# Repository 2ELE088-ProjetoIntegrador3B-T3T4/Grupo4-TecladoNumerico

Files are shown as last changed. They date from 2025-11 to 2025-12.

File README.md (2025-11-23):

# Grupo 4 - TecladoNumerico

Grupo 4 - Teclado Numérico
Composto por Gabriel Trindade Benatti Frizzo, Matheus Rodrigues Garcia e Vitor Hugo Domingues Bogo

## Motivação e justificativa

A escolha do projeto de teclado numérico com switches mecânicos - o componente que efetivamente realiza o acionamento da tecla - se deu pela sua complexidade balanceada, bem como a sua utilidade no cotidiano.

Os membros do grupo veem o periférico como um bem que pode ser usado para auxiliar usuários que trabalham em ambientes laboratoriais e industrias de áreas com grande utilização de números, operações e símbolos matemáticos.

Não só isso mas com pequenas alterações existe a possibilidade de diferenciadas empresas utilizarem o teclado da forma que desejarem, podendo modificar o produto de forma relativamente simples em busca de remapear as teclas para se adequar a situação. Tais modificações incluem, mas não estão limitadas a modificar o digito que cada tecla se referencia, realizar aperto de 2 ou mais teclas com apenas 1 tecla ou mapeamento de comandos internos do sistema operacional, podendo assim realizar trabalhos repetitivos em busca de facilitar a vida do usuário.

Quanto ao uso de switches mecânicos, o uso se dá pela alta durabilidade e confiabilidade em relação ao sistema de teclados por membrana.

##  Objetivos

É esperado que sejam atingidos alguns critérios mínimos para a melhor experiência do usuário, como:

- Personalização e ergonomia: O teclado conta com o sistema de teclas hot-swappable, ou seja, switches facilmente trocáveis por conta da falta de solda, e sim por serem encaixadas manualmente na PCB do teclado.
  - Isso permite que o usuário faça a troca sem grandes dificuldades das teclas de acordo com sua preferência ou necessidade, desde que a pinagem dos novos switches seja compatível com a presente na PCB.

- Os switches são fabricados em diversas forças de atuação, distâncias mínimas e máximas para o clique, níveis de som ao pressionar as teclas e sensações táteis distintas, tornando sua variabilidade enorme.

- O sistema mecânico também possibilita a troca das keycaps - peça que cobre o topo das teclas, rotulando a função de cada uma - à bel-prazer do consumidor, de acordo com sua estética, material e topografia.
  - Com esses dois últimos tópicos buscamos não só dar uma ferramenta nas mãos do usuário como também deixamos a possibilidade de customização própria do usuário em aberto, caso esse venha a desejar.
    > A intenção é que o produto venha completamente funcional para o usuário, que se quiser fazer modificações terá de buscar por si só, aproveitando das comodidades oferecidas para a customização.

- Durabilidade e performance: O estimado para o teclado é que suporte entre 30 e 70 milhões de cliques por tecla, como é estimado para qualquer teclado mecânico.

## Descrição e Funcionamento do Sistema

O sistema tem uma funcionalidade simples, afinal seu único objetivo é "enviar um ou mais sinais para um computador, e que esses sinas sejam entendidos com uma letra do alfabeto e que faça parte do QWERTY"

Portanto, para atingir o objetivo pretendido, o projeto segue a seguinte lógica de funcionamento:

- o microcontrolador STM32F103C8T6 é o centro do projeto, ele será responsável por dialogar com o computador pela porta USB-C, e interpretar o  comportamento da matriz de teclas para saber quando uma foi apertada ou não.
- A matriz de teclas é responsável é onde as teclas estão arranjadas em linhas e colunas (em nosso caso, 3 colunas e 5 linhas), com isso podemos gastar menos GPIOs do microcontrolador e ainda assim ter uma boa quantidade de teclas.
- Por fim o outro componente principal é a entrada USB-C, cujo dela será alimentado todo o sistema da placa e a conversação entre o microcontrolador e o computador é possibilitada.

## Resultados Esperados

O resultado final é um teclado numérico robusto, modular e personalizável, que pode ser utilizado tanto como um periférico de computador quanto como parte de sistemas embarcados, calculadoras, painéis de controle industrial, cofres eletrônicos e sistemas de autenticação.

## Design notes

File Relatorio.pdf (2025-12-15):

Título do artigo
Montagem de um teclado numérico utilizando um STM32F103C8T6

Autores
Gabriel Trindade Benatti Frizzo, Matheus Rodrigues Garcia*, Vitor Hugo Domingues Bogo.

Afiliações
Universidade Estadual de Londrina (UEL), Rodovia Celso Garcia Cid, PR-445, Km 380 – Campus Universitário, Londrina – PR, 86057-970, Brasil.

Resumo
O produto consiste em um teclado numérico mecânico com layout de teclas 3x5 com conexão por fio. O teclado é controlado por um STM32F103C8T6 e usa sistema hot-swappable de teclas.

Palavras-chave
Teclado numérico 3×5, sistemas embarcados, sensores de baixo custo.

Tabela de especificações

Nome do hardware | Nome do hardware que você desenvolveu/customizou
Area tem ´ ática | • Geral
Tipo de hardware | • Engenharia elétrica e ciência da computação
Análogo comercial mais próximo | Numérico matricial comercial (3×5)
Licença de código aberto | CERN Open Hardware License Version 2 – Permissive (CERN-OHL-P v2).
Custo do hardware | Aproximadamente 20–30 USD.
Repositório dos arquivos-fonte | https://github.com/2ELE088-ProjetoIntegrador3B-T3T4/Grupo4-TecladoNumerico (https://github.com/2ELE088-ProjetoIntegrador3B-T3T4/Grupo4-TecladoNumerico)

### 1. Hardware no contexto

O hardware desenvolvido consiste em um teclado mecânico programável baseado no microcontrolador, o qual é o STM32F103C8T6. Ele se enquadra na categoria de dispositivos HID (Human Interface Device) abertos, permitindo total reprodutibilidade e modificação por parte do usuário.
Projetos de hardware aberto semelhantes incluem teclados amplamente utilizados em comunidades maker, como o Ferris, Corne, Lily58 e outros dispositivos baseados em firmwares open source como QMK e ZMK. Assim como esses projetos, o teclado apresentado oferece esquemáticos, arquivos Gerber e firmware totalmente acessíveis.
Em contraste, teclados proprietários amplamente disponíveis no mercado como os modelos da Keychron, Logitech, Corsair e Razer geralmente não oferecem acesso aos arquivos de projeto também limitam a personalização do firmware e possuem componentes que não podem ser substituídos ou modificados pelo usuário. Esse projeto é diferente por sua total abertura, simplicidade de fabricação e possibilidade de customização tanto eletrônica quanto mecânica.
Dessa forma, o hardware se enquadra em dispositivos abertos projetados para facilitar estudos de microcontroladores, experimentação em eletrônica digital e desenvolvimento de interfaces personalizadas, mantendo compatibilidade com padrões HID.

### 2. Descrição do hardware

Ao contrário de teclados comerciais de função única, este hardware opera em três camadas de customização simultâneas:
Camada Física (Hot-Swappable): O sistema de soquetes permite que qualquer usuário, sem conhecimento de solda, troque os interruptores mecânicos em segundos. Isso possibilita adaptar a força de atuação (de 35g a 95g), tipo de feedback (tátil, linear, clique) e som conforme a preferência do usuário ou necessidade (ex.: laboratório silencioso vs. ambiente industrial).
Camada de Firmware: O teclado roda o firmware de código aberto, com suporte à interface ST-Link para reprogramação em tempo real. Cada tecla pode ser remapeada dinamicamente para qualquer código, macro ou combinação complexa.
Camada de Aplicação: A interface física é separada da lógica de aplicação, permitindo que o mesmo hardware sirva como controle para diferentes softwares (ImageJ, LabView, Python scripts) com uma certa reprogramação do software do teclado.

Arquivos de projeto

- Os arquivos completos de projeto estão disponíveis no repositório GitHub:
Repositório do projeto no GitHub (https://github.com/2ELE088-ProjetoIntegrador3B-T3T4/Grupo4-TecladoNumerico)

Arquivos CAD: Projeto completo no Altium Designer, incluindo esquemático, layout da PCB e arquivos de fabricação (Gerber) na pasta /Teclado/Project Outputs for teclado.

Impressão 3D: Arquivos de modelagem 3D da caixa do teclado, fornecidos em formatos STL e STEP na pasta /3D.

Eletrônica: Layouts, esquemáticos e bibliotecas relacionados ao hardware na pasta /Teclado/.

Software e firmware: Projeto STM32CubeIDE com o firmware desenvolvido para o controlador STM32F103C8T6, localizado na pasta /Firmware.

### 3. Resumo dos arquivos de projeto

Nome do arquivo de projeto | Tipo de arquivo | Descrição do arquivo
teclado/SqTeclado.SchDoc | CAD (Altium) | Esquemático completo do teclado numérico.
teclado/PCBtc.PcbDoc | CAD (Altium) | Layout da PCB do teclado.
Gerber Files.zip | Gerber | Arquivos de fabricação para PCB.
Firmware/.project | Firmware (CubeIDE) | Código-fonte para o STM32F103C8T6.
3D/CaixaTeclado.stl | 3D (STL) | Modelo para impressão 3D da caixa do teclado.
3D/TampaTeclado.stl | 3D (STL) | Tampa da caixa do teclado para impressão 3D.
3D/Keycap.stl | 3D (STL) | Modelo para impressão 3D das keycaps uti-lizadas no teclado.
3D/Teclado.step | 3D (STEP) | Modelo para 3D do teclado.
README.md | Documentação | Instruções gerais e organização do repositório.

Cada arquivo listado acima está detalhado no repositório GitHub.

Bill of materials

### 4. Resumo da Bill of materials

Designador | Componente | Quan tidade | Custo por unidade - moeda | Custo total -moeda | Fonte do material | Tipo de material
C5, C8 | CL10B105KP8NNNC | 2 | 0.005 USD | 0.05 USD | Digi-Key (https://www.digikey.com.br/pt/products/detail/samsung-electro-mechanics/CL10B105KP8NNNC/3887604) | -Cerâmica
C1, C2, C3, C4, C9, C12, C13 | CC0603KRX7R7BB104 | 7 | 0.006 USD | 0.06 USD | Digi-Key (https://www.digikey.com.br/pt/products/detail/yageo/CC0603KRX7R7BB104/302822) | -Cerâmica
R2, R4, R9, R10, R11, R12, R13, R14 | CRCW060310K0FKEA | 8 | 0.03 USD | 0.3 USD | Digi-Key (https://www.digikey.com.br/pt/products/detail/vishay-dale/CRCW060310K0FKEA/1174782) | -Metal
C6, C7 | CL05C330JB5NNNC | 2 | 0.003 USD | 0.03 USD | Digi-Key (https://www.digikey.com.br/pt/products/detail/samsung-electro-mechanics/CL05C330JB5NNNC/3886930) | -Cerâmica
C10 | CL10B223KB8WPNC | 1 | 0.1 USD | 0.1 USD | Digi-Key (https://www.digikey.com.br/pt/products/detail/samsung-electro-mechanics/CL10B223KB8WPNC/5961018) | -Cerâmica
J1 | SBH11-PBPC-D10-ST-BK | 1 | 0.41 USD | 0.41 USD | Digi-Key (https://www.digikey.com.br/pt/products/detail/sullins-connector-solutions/SBH11-PBPC-D10-ST-BK/1990065) | -Metal
Y1 | ECS-80-20-5PXDU-TR | 1 | 0.45 USD | 0.45 USD | Digi-Key (https://www.digikey.com.br/pt/products/detail/ecs-inc/ECS-80-20-5PXDU-TR/1693466) | -Cerâmica
D1–D15 | 1N4148WX-TP | 15 | 0.061 USD | 0.915 USD | Digi-Key (https://www.digikey.com.br/pt/products/detail/mcc-micro-commercial-components/1N4148WX-TP/717197) | -Semicondutor
F1 | ERBRD0R50X | 1 | 0.29 USD | 0.29 USD | Digi-Key (https://www.digikey.com.br/pt/products/detail/panasonic-electronic-components/ERB-RD0R50X/2796780) | -Metal
U2–U4, U6–U17 | 4958 | 1 | 4.95 USD | 4.95 USD | Digi-Key (https://www.digikey.com.br/pt/products/detail/adafruit-industries-llc/4958/13997772) | -Metal
U5 | STM32F103C8T6 | 1 | 6.08 USD | 6.08 USD | Digi-Key (https://www.digikey.com.br/pt/products/detail/stmicroelectronics/STM32F103C8T6/1646338) | -Semicondutor
C11 | LMK107BBJ106MALT | 1 | 0.08 USD | 0.08 USD | Digi-Key (https://www.digikey.com.br/pt/products/detail/taiyo-yuden/LMK107BBJ106MALT/3662195) | -Cerâmica
R6, R7 | RK73H1ETTP5101F | 2 | 0.1 USD | 0.2 USD | Digi-Key (https://www.digikey.com.br/pt/products/detail/koa-speer-electronics-inc/RK73H1ETTP5101F/9844118) | -Metal
R5 | ERJ-3EKF1004V | 1 | 0.1 USD | 0.1 USD | Digi-Key (https://www.digikey.com.br/pt/products/detail/panasonic-electronic-components/ERJ-3EKF1004V/196033) | -Semicondutor
R1 | ERA-2AEB152X | 1 | 0.1 USD | 0.1 USD | Digi-Key (https://www.digikey.com.br/pt/products/detail/panasonic-electronic-components/ERA-2AEB152X/1706009) | -Semicondutor
U19 | RT9193-33GB | 1 | 0.17732 USD | 531.96 USD | Digi-Key (https://www.digikey.com.br/pt/products/detail/richtek-usa-inc/RT9193-33GB/2470048) | -Semicondutor
X1–X15 | MX1A-C1NN | 15 | 1.25 USD | 18.75 USD | Digi-Key (https://www.digikey.com.br/pt/products/detail/cherry-americas-llc/mx1a-c1nn/16998) | -Metal
U1 | USB4110-GF-A | 1 | 1.23 USD | 1.23 USD | Digi-Key (https://www.digikey.com.br/pt/products/detail/gct/USB4110-GF-A/10384547) | -Semicondutor
U18 | USBLC6-2SC6 | 1 | 0.36 USD | 0.36 USD | Digi-Key (https://www.digikey.com.br/pt/products/detail/stmicroelectronics/USBLC6-2SC6/1040559) | -Semicondutor
R3, R8 | CR0402AJ/-000GAS | 2 | 0.1 USD | 0.2 USD | Digi-Key (https://www.digikey.com.br/pt/products/detail/bourns-inc/CR0402AJ-000GAS/10240110) | -Metal

### 5. Instruções de construção

1. Fabricação da PCB
- Utilize os arquivos Gerber disponibilizados em Gerber Files/.
- Envie os arquivos para um fabricante de PCB (por exemplo, JLCPCB, PCBWay, OSH Park ou equivalente).
- Recomendações sugeridas:

– Espessura da placa: 1.6 mm
– Máscara de solda: ”””””””””””””””””””””””””””””””verde (ou outra cor disponível)
– Acabamento superficial: HASL ou ENIG
- Opcionalmente, solicite a montagem SMT direta pelo fabricante, utilizando a Bill of Materials e o arquivo de posicionamento.
2. Montagem dos componentes eletrônicos

Há duas possibilidades de montagem:

### 2.1. Montagem pelo fabricante

- A maioria dos componentes SMD pode ser montada automaticamente.
- Esta opção é recomendada para precisão e confiabilidade.

### 2.2. Montagem manual pelo usuário

- Solde primeiro os componentes SMD (resistores, capacitores, diodos e ICs).
- Utilize ferro de solda entre 300–350 °C, com ponta fina.
- Após isso, solde os componentes PTH, como:

– Switches mecânicos MX,
– Conector USB,
– Header J1.
- Verifique cuidadosamente a polaridade dos seguintes componentes:

– Diodos 1N4148WX-TP,
– Regulador U19,
– Microcontrolador STM32F103C8T6,
– Proteção USBLC6-2SC6.
- Antes de energizar a placa, confira a ausência de curtos-circuitos.
3. Programação do firmware
- Abra o projeto disponibilizado em Firmware/ no STM32CubeIDE.
- Conecte um programador ST-Link ao conector J1.
- Compile e carregue o firmware no microcontrolador STM32F103C8T6.
- Após a gravação, desconecte o programador e alimente a placa via USB-C.

4. Montagem mecânica da caixa
- Imprima os arquivos 3D da caixa e da tampa disponíveis na pasta 3D/.
- Insira a PCB na caixa, alinhando os furos aos suportes internos.
- Utilize parafusos M3 para fixar a PCB.
- Encaixe a tampa superior.
- Instale as keycaps nos switches MX.
5. Pontos de atenção e segurança
- Evite contato com pads sensíveis durante a soldagem para prevenir danos eletrostáticos.
- Não exceda temperaturas adequadas de soldagem para evitar descolamento de trilhas.
- Utilize óculos de proteção ao soldar ou realizar cortes.
- Inspecione visualmente a placa antes de energizá-la.
- Mantenha a placa afastada de líquidos e fontes de calor extremos.

### 6. Instruções de operação

Procedimento de Operação

- Conecte o teclado ao computador por meio da porta USB-C.O dispositivo será reconhecido automaticamente como um teclado padrão (HID).
- Após a conexão, o teclado estará pronto para uso imediato, não é necessária instalação de drivers extras.
- Pressione qualquer uma das teclas disponíveis, cada acionamento enviará o respectivo código de tecla ao computador.
- Caso o computador não reconheça o dispositivo, remova o cabo USB-C e reconecte-o, verificando também a integridade do cabo.

Cuidados e Segurança

- Evite contato com líquidos. Exposição à água ou outros fluidos pode causar curto-circuito, falha permanente ou risco elétrico.
- Não derrube o produto. Impactos fortes podem danificar a PCB, switches mecânicos, soldas ou o microcontrolador.
- Não aplique força excessiva ao pressionar as teclas; os switches mecânicos possuem limite físico de operação.
- Não tente abrir ou modificar o hardware sem conhecimento técnico, pois isso pode causar danos irreversíveis e perda de garantia.
- Utilize somente cabos USB-C de boa qualidade para garantir alimentação estável e comunicação adequada.

### 7. Validação e caracterização

Validação Funcional

Para demonstrar a operação adequada do hardware, foram realizados testes diretos conectando o teclado a um computador por meio da interface USB-C. O microcontrolador STM32F103C8T6 foi programado para atuar como um dispositivo HID (Human Interface Device), enviando códigos de teclas ao sistema operacional.
Os seguintes procedimentos foram executados:
- Conexão do dispositivo a diferentes computadores (Windows, Linux e MacOS) para verificar reconhecimento automático do teclado.
- Teste individual de todas as 15 teclas mecânicas (switches MX) para garantir detecção correta e ausência de falhas de acionamento.
- Verificação da temporização de debounce via firmware, assegurando que nenhum acionamento múltiplo (bouncing) ocorresse.
- Inspeção visual e elétrica da PCB para confirmar continuidade e ausência de curtos.

A validação confirmou que o teclado é reconhecido corretamente em todos os sistemas testados e que todas as teclas apresentam leitura estável e sem erros.

Caracterização do Desempenho

A caracterização do teclado considerou parâmetros elétricos e mecânicos relevantes:

- Tempo de resposta: menor que 5 ms entre o acionamento da tecla e o envio do código HID.
- Consumo de corrente: aproximadamente 20–35 mA em operação contínua.
- Tensão de operação: 5 V fornecidos via USB.
- Ruído elétrico: filtrado adequadamente por capacitores de desacoplamento, permitindo operação estável.
- Confiabilidade dos switches: vida útil estimada em mais de 50 milhões de acionamentos (característica padrão dos switches MX).
- Precisão da leitura: 100% de detecção de teclas durante testes contínuos.

Capacidades e Limitações

Capacidades:

- Compatibilidade completa com computadores que suportam dispositivos HID via USB.
- Alta durabilidade e sensação tátil devido aos switches mecânicos MX.
- Debounce implementado via firmware, garantindo leitura confiável.
- Baixo consumo de energia devido ao uso do microcontrolador STM32.
- Latência muito baixa, praticamente imperceptível ao usuário.

Limitações:

- Não possui retroiluminação integrada.
- Quantidade fixa de teclas (15), não expansível sem alteração da PCB.
- O dispositivo depende do cabo USB-C para alimentação e operação (não possui bateria).
- Não oferece personalização avançada via software sem recompilar o firmware.

—————————————————————————————————————————

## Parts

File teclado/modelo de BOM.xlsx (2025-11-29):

Designator | LibRef | Footprint
C5, C8 | CL10B105KP8NNNC | cap 105 0603
C1, C2, C3, C4, C9, C12, C13 | CC0603KRX7R7BB104 | Cap 104 0603
R2, R4, R9, R10, R11, R12, R13, R14 | CRCW060310K0FKEA | Resistor 10k 0603
C10 | GRM033R60J223KE01D | cap 223 0603
C6, C7 | CL05C330JB5NNNC | C 33pf 0402
J1 | SBH11-PBPC-D10-ST-BK | Conector 20 pinos p/ programação
Y1 | ECS-80-20-5PXDU-TR | Cristal 8MHz
D1, D2, D3, D4, D5, D6, D7, D8, D9, D10, D11, D12, D13, D14, D15 | 1N4148WX-TP | Diodo
F1 | ERBRD0R50X | Fuse
U2, U3, U4, U6, U7, U8, U9, U10, U11, U12, U13, U14, U15, U16, U17 | 4958 | Suporte Hot-Swap
U5 | STM32F103C8T6 | STM32F103C8T6
C11 | LMK107BBJ106MALT | cap 106 0603
R6, R7 | RK73H1ETTP5101F | R 5.1k 0402
R5 | ERJ-3EKF1004V | R 1Mr 0603
R1 | ERA-2AEB152X | R 1.5k 0402
U19 | RT9193-33GB | Regulador 5v->3v
U1 | USB4110-GF-A | USB-C
U18 | USBLC6-2SC6 | Potege estatica
R3, R8 | CR0402AJ/-000GAS | R0

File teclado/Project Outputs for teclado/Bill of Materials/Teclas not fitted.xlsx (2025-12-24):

Line # | Description | Designator | Quantity | Comment | Supplier Part Number | Supplier Subtotal per Board 1 | Supplier Stock 1 | Supplier Packaging 1 | Supplier Order Qty 1 | Supplier Currency 1 | Manufacturer 1 | Manufacturer Part Number 1 | Manufacturer Lifecycle 1 | Supplier 1 | Supplier Part Number 1 | Supplier Unit Price 1 | Supplier Subtotal 1
 | 10V 1uF X7R ±10% 0603 Multilayer Ceramic Capacitors MLCC - SMD/SMT ROHS | C9, C14 | 2 | CL10B105KP8NNNC | 1276-1946-1-ND | 0.01 | 3540967 | Cut Tape | 10 | USD | Samsung Electro-Mechanics | CL10B105KP8NNNC | Volume Production | DigiKey | 1276-1946-1-ND | 0.005 | 0.05
 | 16V 100nF X7R ±10% 0603 Multilayer Ceramic Capacitors MLCC - SMD/SMT ROHS | C1, C3, C4, C5, C6, C7, C10, C13 | 8 | CC0603KRX7R7BB104 | 311-1088-1-ND | 0.048 | 5424503 | Cut Tape | 10 | USD | Yageo Group | CC0603KRX7R7BB104 | Volume Production | DigiKey | 311-1088-1-ND | 0.006 | 0.06
 | 100Mw Thick Film Resistors 100Ppm/ 5% 1.5K 0603 Chip Resistor Surface Mount Rohs | R3 | 1 | RC0603JR-071K5L | 311-1.5KGRCT-ND | 0.1 | 687335 | Cut Tape | 1 | USD | Yageo Group | RC0603JR-071K5L | Volume Production | DigiKey | 311-1.5KGRCT-ND | 0.1 | 0.1
 | 100mW Thick Film Resistors ±1% ±100ppm/℃ 10kΩ 0603 Chip Resistor - Surface Mount ROHS | R5, R6, R7, R8, R9, R10, R11, R12 | 8 | CRCW060310K0FKEA | 541-10.0KHCT-ND | 0.24 | 2856834 | Cut Tape | 10 | USD | Vishay | CRCW060310K0FKEA | Volume Production | DigiKey | 541-10.0KHCT-ND | 0.03 | 0.3
 | 0603 27 pF 50 V ±1 % Tolerance NP0 SMT Multilayer Ceramic Capacitor | C2, C8 | 2 | CC0603FRNPO9BN270 | 311-3892-1-ND | 0.3 | 50604 | Cut Tape | 2 | USD | Yageo Group | CC0603FRNPO9BN270 | Volume Production | DigiKey | 311-3892-1-ND | 0.15 | 0.3
 | Ceramic Capacitor, Multilayer, Ceramic, 50V, 10% +Tol, 10% -Tol, X7R, +-15% TC, 22nF, Surface Mount, 0603 inch | C11 | 1 | CL10B223KB8WPNC | 1276-6534-1-ND | 0.1 | 841892 | Cut Tape | 1 | USD | Samsung Electro-Mechanics | CL10B223KB8WPNC | Volume Production | DigiKey | 1276-6534-1-ND | 0.1 | 0.1
 | Conn Shrouded Header (4 Sides) HDR 20 POS 2.54mm Solder RA Side Entry Thru-HoleC-Grid Tray | J1 | 1 | 70247-2051 | 23-0702472051-ND | 3.89 | 2615 | Bulk | 1 | USD | Molex | 70247-2051 | Volume Production | DigiKey | 23-0702472051-ND | 3.89 | 3.89
 | Crystal 8MHz ±30ppm (Tol) ±100ppm (Stability) 20pF FUND 60Ohm 2-Pin SMD T/R | Y1 | 1 | ECS-80-20-5PXDU-TR | XC1526CT-ND | 0.45 | 7422 | Cut Tape | 1 | USD | ECS International | ECS-80-20-5PXDU-TR | Volume Production | DigiKey | XC1526CT-ND | 0.45 | 0.45
 | Fuse Chip Fast Acting 0.5A 32V SMD Solder Pad 0603 1.6 X 0.8 X 0.54mm T/R UL/cUL | F1 | 1 | ERB-RE0R50V | P15127CT-ND | 0.31 | 2919 | Cut Tape | 1 | USD | Panasonic | ERB-RE0R50V | Volume Production | DigiKey | P15127CT-ND | 0.31 | 0.31
 | GENERAL PURPOSE CHIP RESISTOR Metal Glaze/thick Film, 0.1W, 0ohm, Surface Mount, 0603 | R4 | 1 | RC0603JR-070RL | 311-0.0GRCT-ND | 0.1 | 2939930 | Cut Tape | 1 | USD | Yageo Group | RC0603JR-070RL | Volume Production | DigiKey | 311-0.0GRCT-ND | 0.1 | 0.1
 | Kailh Switch Sockets For Mx-Compatible Mechanical Keys - 20 Pack |Adafruit 4958 | U2, U3, U4, U6, U7, U8, U9, U10, U11, U12, U13, U14, U16, U17, U18 | 15 | 4958 | 1528-4958-ND | 74.25 | 37 | Bulk | 15 | USD | Adafruit Industries | 4958 | Unknown | DigiKey | 1528-4958-ND | 4.95 | 74.25
 | MCU 32-bit STM32F1 ARM Cortex M3 RISC 64KB Flash 2.5V/3.3V 48-Pin LQFP Tray | U5 | 1 | STM32F103C8T6 | 497-6063-ND | 6.08 | 3373 | Tray | 1 | USD | STMicroelectronics | STM32F103C8T6 | Volume Production | DigiKey | 497-6063-ND | 6.08 | 6.08
 | Multilayer Ceramic Capacitors (High dielectric type), 10V, 10 uF, ± 20 %, 0603, X5R, RoHS | C12 | 1 | LMK107BBJ106MALT | 587-3258-1-ND | 0.08 | 861176 | Cut Tape | 1 | USD | TAIYO YUDEN | LMK107BBJ106MALT | Volume Production | DigiKey | 587-3258-1-ND | 0.08 | 0.08
 | Rectifier Diode Schottky 40V 0.03A 2-Pin SOD-323 T/R / DIODE SCHOTTKY 30V 30MA SOD323 | D1, D2, D3, D4, D5, D6, D7, D8, D9, D10, D11, D12, D13, D14, D15 | 15 | RB751V40T1G | RB751V40T1GOSCT-ND | 1.2 | 326728 | Cut Tape | 15 | USD | onsemi | RB751V40T1G | Volume Production | DigiKey | RB751V40T1GOSCT-ND | 0.08 | 1.2
 | Res Thick Film 0603 5.1K Ohm 1% 0.1W(1/10W) ±100ppm/C Pad SMD T/R | R1, R2 | 2 | RC0603FR-075K1L | 311-5.10KHRCT-ND | 0.014 | 618540 | Cut Tape | 10 | USD | Yageo Group | RC0603FR-075K1L | Volume Production | DigiKey | 311-5.10KHRCT-ND | 0.007 | 0.07
 | RT9193 Series 300 mA 3.3 V Ultra-Low Noise Ultra-Fast CMOS LDO Regulator-SC-70-5 | U19 | 1 | RT9193-33GB | 1028-1014-1-ND |  |  |  |  |  | Richtek | RT9193-33GB | Obsolete
 | USB Connector, 16 Contact(s), Male, Right Angle, Surface Mount Terminal, Locking, Receptacle | U1 | 1 | USB4110-GF-A | 2073-USB4110-GF-A-1-ND | 1.23 | 38043 | Cut Tape | 1 | USD | Global Connector Technology | USB4110-GF-A | Volume Production | DigiKey | 2073-USB4110-GF-A-1-ND | 1.23 | 1.23
 | USBLC6 Series 2 Line 6 V Uni / Bi-Directional ESD Protection - SOT-23-6 | U15 | 1 | USBLC6-2SC6 | 497-5235-1-ND | 0.36 | 126022 | Cut Tape | 1 | USD | STMicroelectronics | USBLC6-2SC6 | Volume Production | DigiKey | 497-5235-1-ND | 0.36 | 0.36

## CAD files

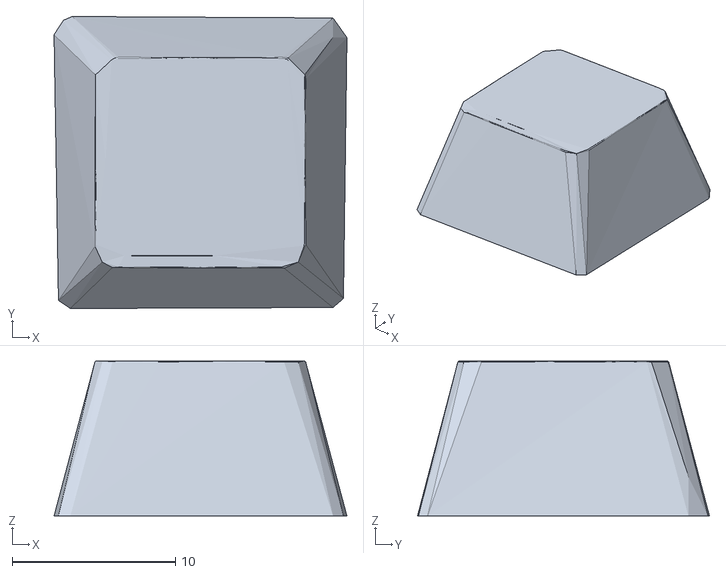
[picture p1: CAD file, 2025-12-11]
3D/Keycap.stl
18.0 x 17.9 x 9.50

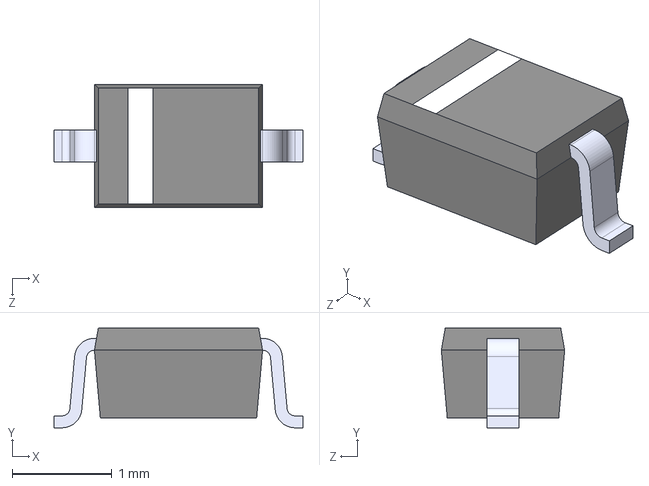
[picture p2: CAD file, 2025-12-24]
teclado/Modelo 3D/Diodo C.step
2.50 x 1.00 x 1.24 mm

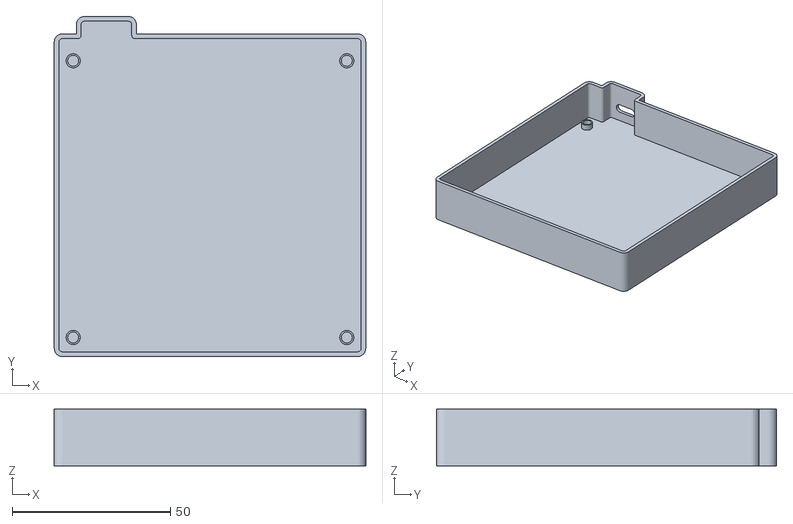
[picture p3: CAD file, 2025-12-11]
3D/CaixaTeclado.stl
98.5 x 107.5 x 18.0

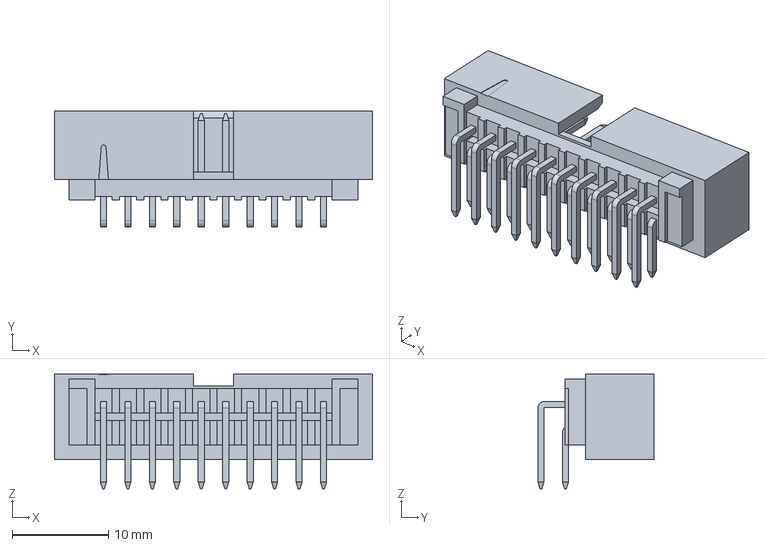
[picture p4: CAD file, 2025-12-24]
teclado/Modelo 3D/conc 20p ang.stp
33.0 x 12.1 x 11.9 mm

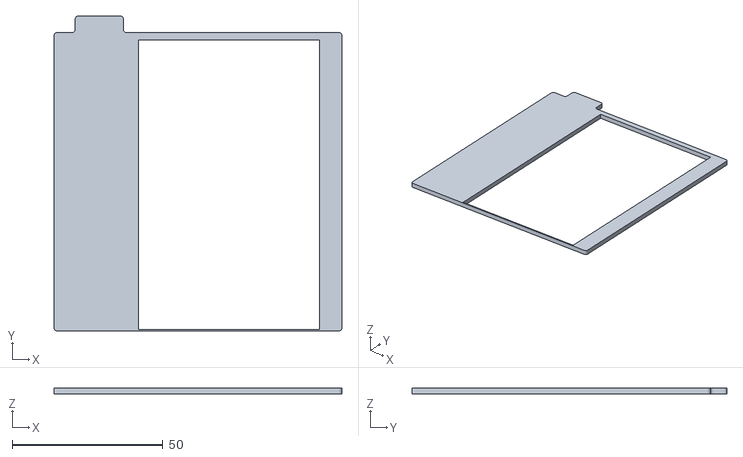
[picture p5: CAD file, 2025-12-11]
3D/TampaTeclado.stl
95.5 x 104.5 x 2.00

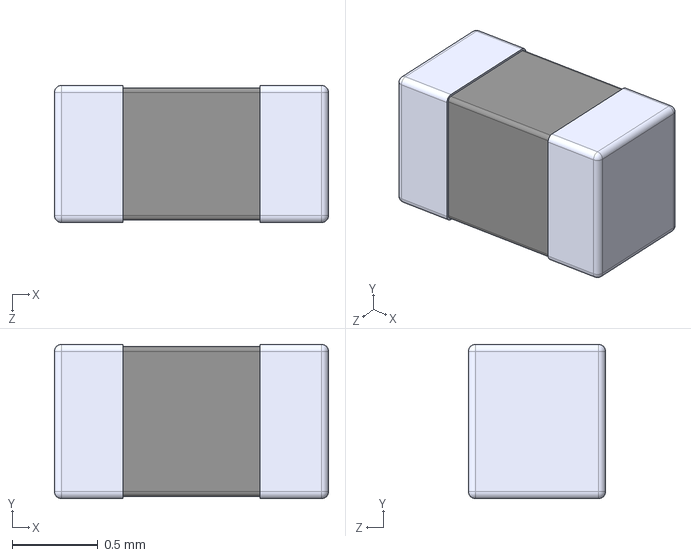
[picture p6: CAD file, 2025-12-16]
teclado/Modelo 3D/cap 27pf 0603.step
1.60 x 0.9 x 0.8 mm

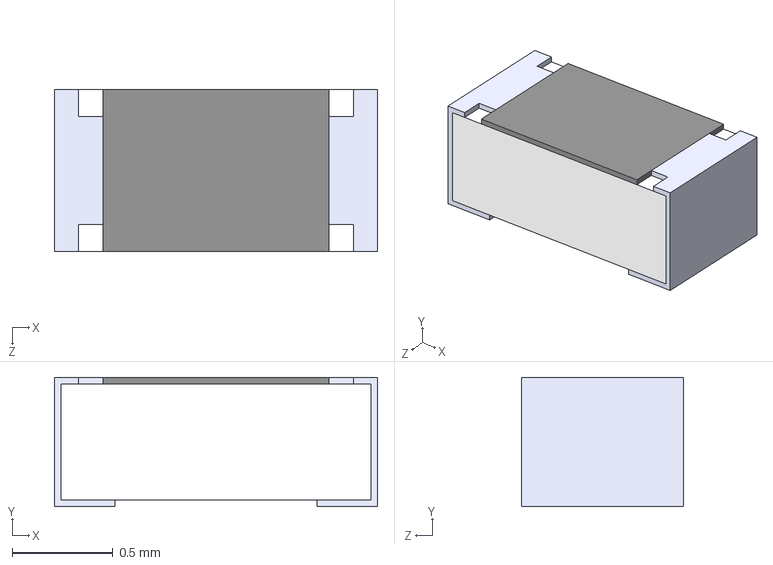
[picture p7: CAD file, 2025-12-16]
teclado/Modelo 3D/F 500ma 0603.STEP
1.60 x 0.64 x 0.8 mm

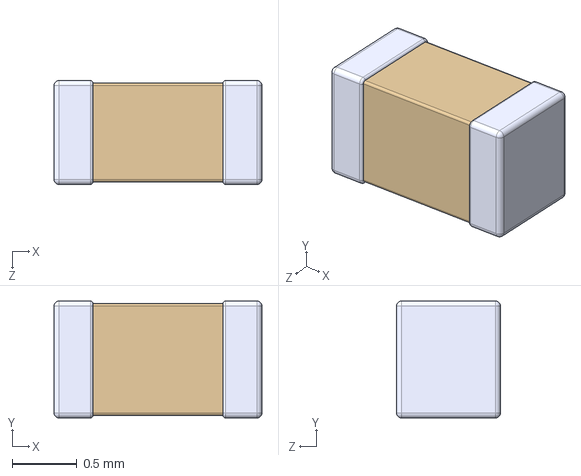
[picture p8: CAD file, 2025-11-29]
teclado/Modelo 3D/cap 223 0603.step
1.60 x 0.9 x 0.8 mm

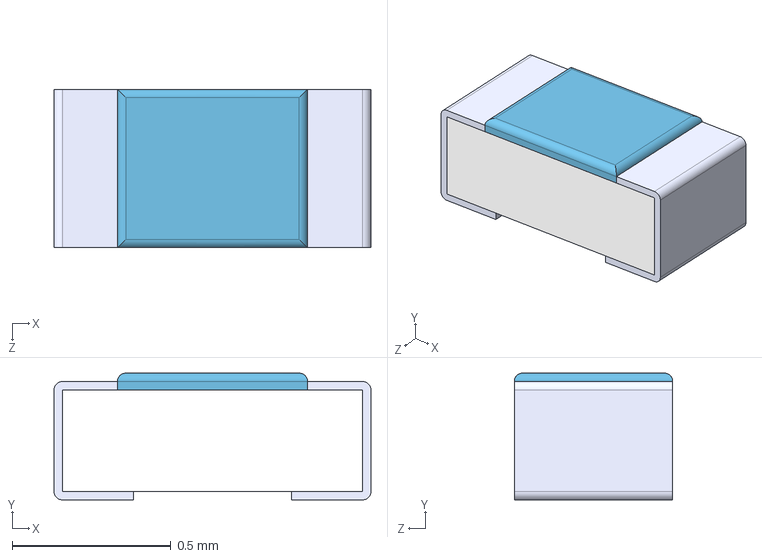
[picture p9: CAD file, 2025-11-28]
teclado/Modelo 3D/R 5.1k 0402.step
1.00 x 0.4 x 0.5 mm

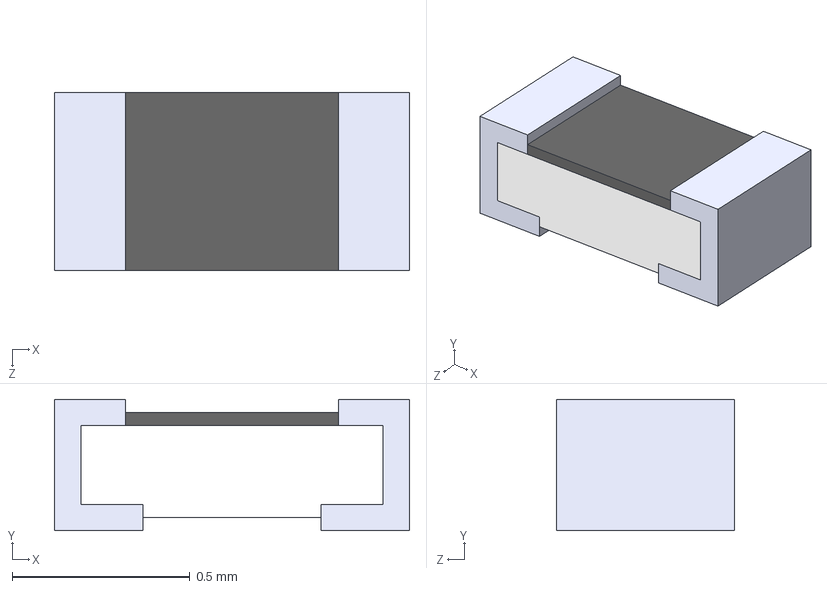
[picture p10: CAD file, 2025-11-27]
teclado/Modelo 3D/R0 0402.STEP
1.00 x 0.37 x 0.5 mm

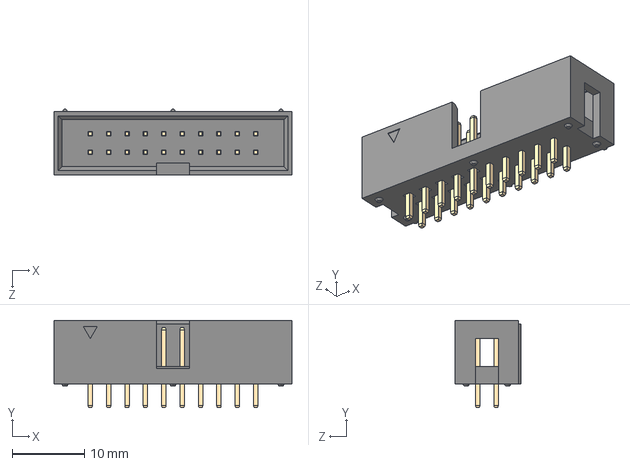
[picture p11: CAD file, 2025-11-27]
teclado/Modelo 3D/conector 20P program.STEP
32.9 x 12.1 x 9.09 mm

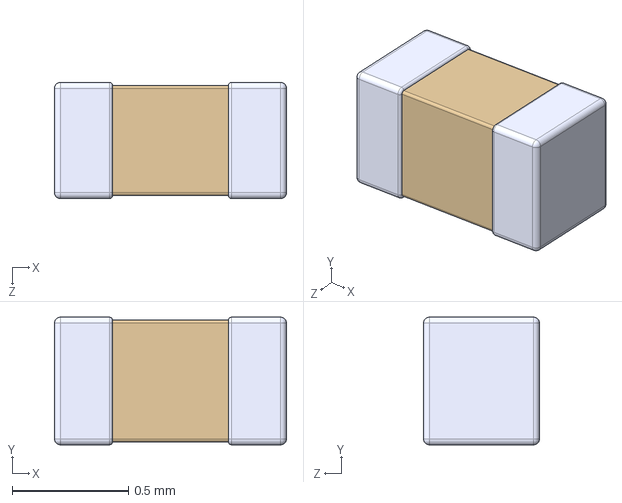
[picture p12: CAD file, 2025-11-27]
teclado/Modelo 3D/C 33pf 0402.STEP
1.00 x 0.55 x 0.5 mm

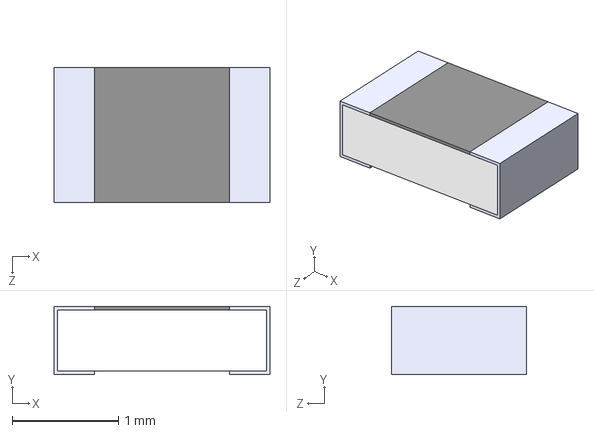
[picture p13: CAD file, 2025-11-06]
teclado/Modelo 3D/R 1.5k 0805.STEP
2.03 x 0.64 x 1.27 mm

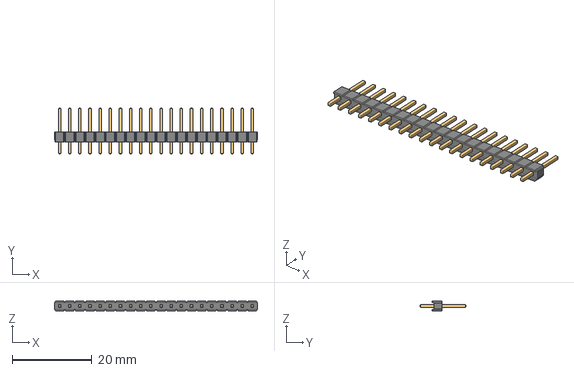
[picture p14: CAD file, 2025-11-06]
teclado/Modelo 3D/conector 1x20.stp
50.8 x 11.5 x 2.54 mm
6130xx11121_PIN x 20

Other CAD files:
teclado/Modelo 3D/con 20p ang 2.stp
teclado/Modelo 3D/swith.STEP
teclado/Modelo 3D/Switche.STEP
teclado/Modelo 3D/fuse.STEP
teclado/Modelo 3D/CRCW060310K0FKEA.STEP
teclado/Modelo 3D/Cap 104 0603.STEP
teclado/Modelo 3D/Diodo.STEP
teclado/Modelo 3D/Protetor curto.step
teclado/Modelo 3D/R 0 0603.STEP
teclado/Modelo 3D/R 1.5k 0402.step
teclado/Modelo 3D/R 1.5k 0603.step
teclado/Modelo 3D/R 1m 0603.step
teclado/Modelo 3D/R 5.1k 0603.step
teclado/Modelo 3D/STM32F103C8T6.STEP
teclado/Modelo 3D/USBC.stp
teclado/Modelo 3D/cap 105 0603.STEP
teclado/Modelo 3D/cap 106 0603.step
teclado/Modelo 3D/cap 20p .STEP
teclado/Modelo 3D/conctor angulado.STEP
teclado/Modelo 3D/conector 3x2.stp
teclado/Modelo 3D/cristal 32,768k.STEP
teclado/Modelo 3D/cristal 8MHZ.STEP
teclado/Modelo 3D/led branco.STEP
teclado/Modelo 3D/led vermelho.step
teclado/Modelo 3D/micro usb.STEP
teclado/Modelo 3D/regulador.STEP
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

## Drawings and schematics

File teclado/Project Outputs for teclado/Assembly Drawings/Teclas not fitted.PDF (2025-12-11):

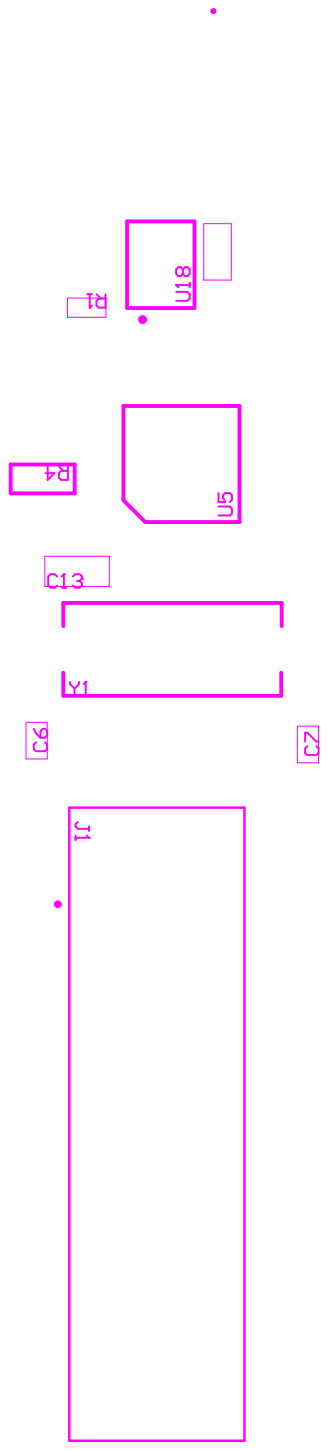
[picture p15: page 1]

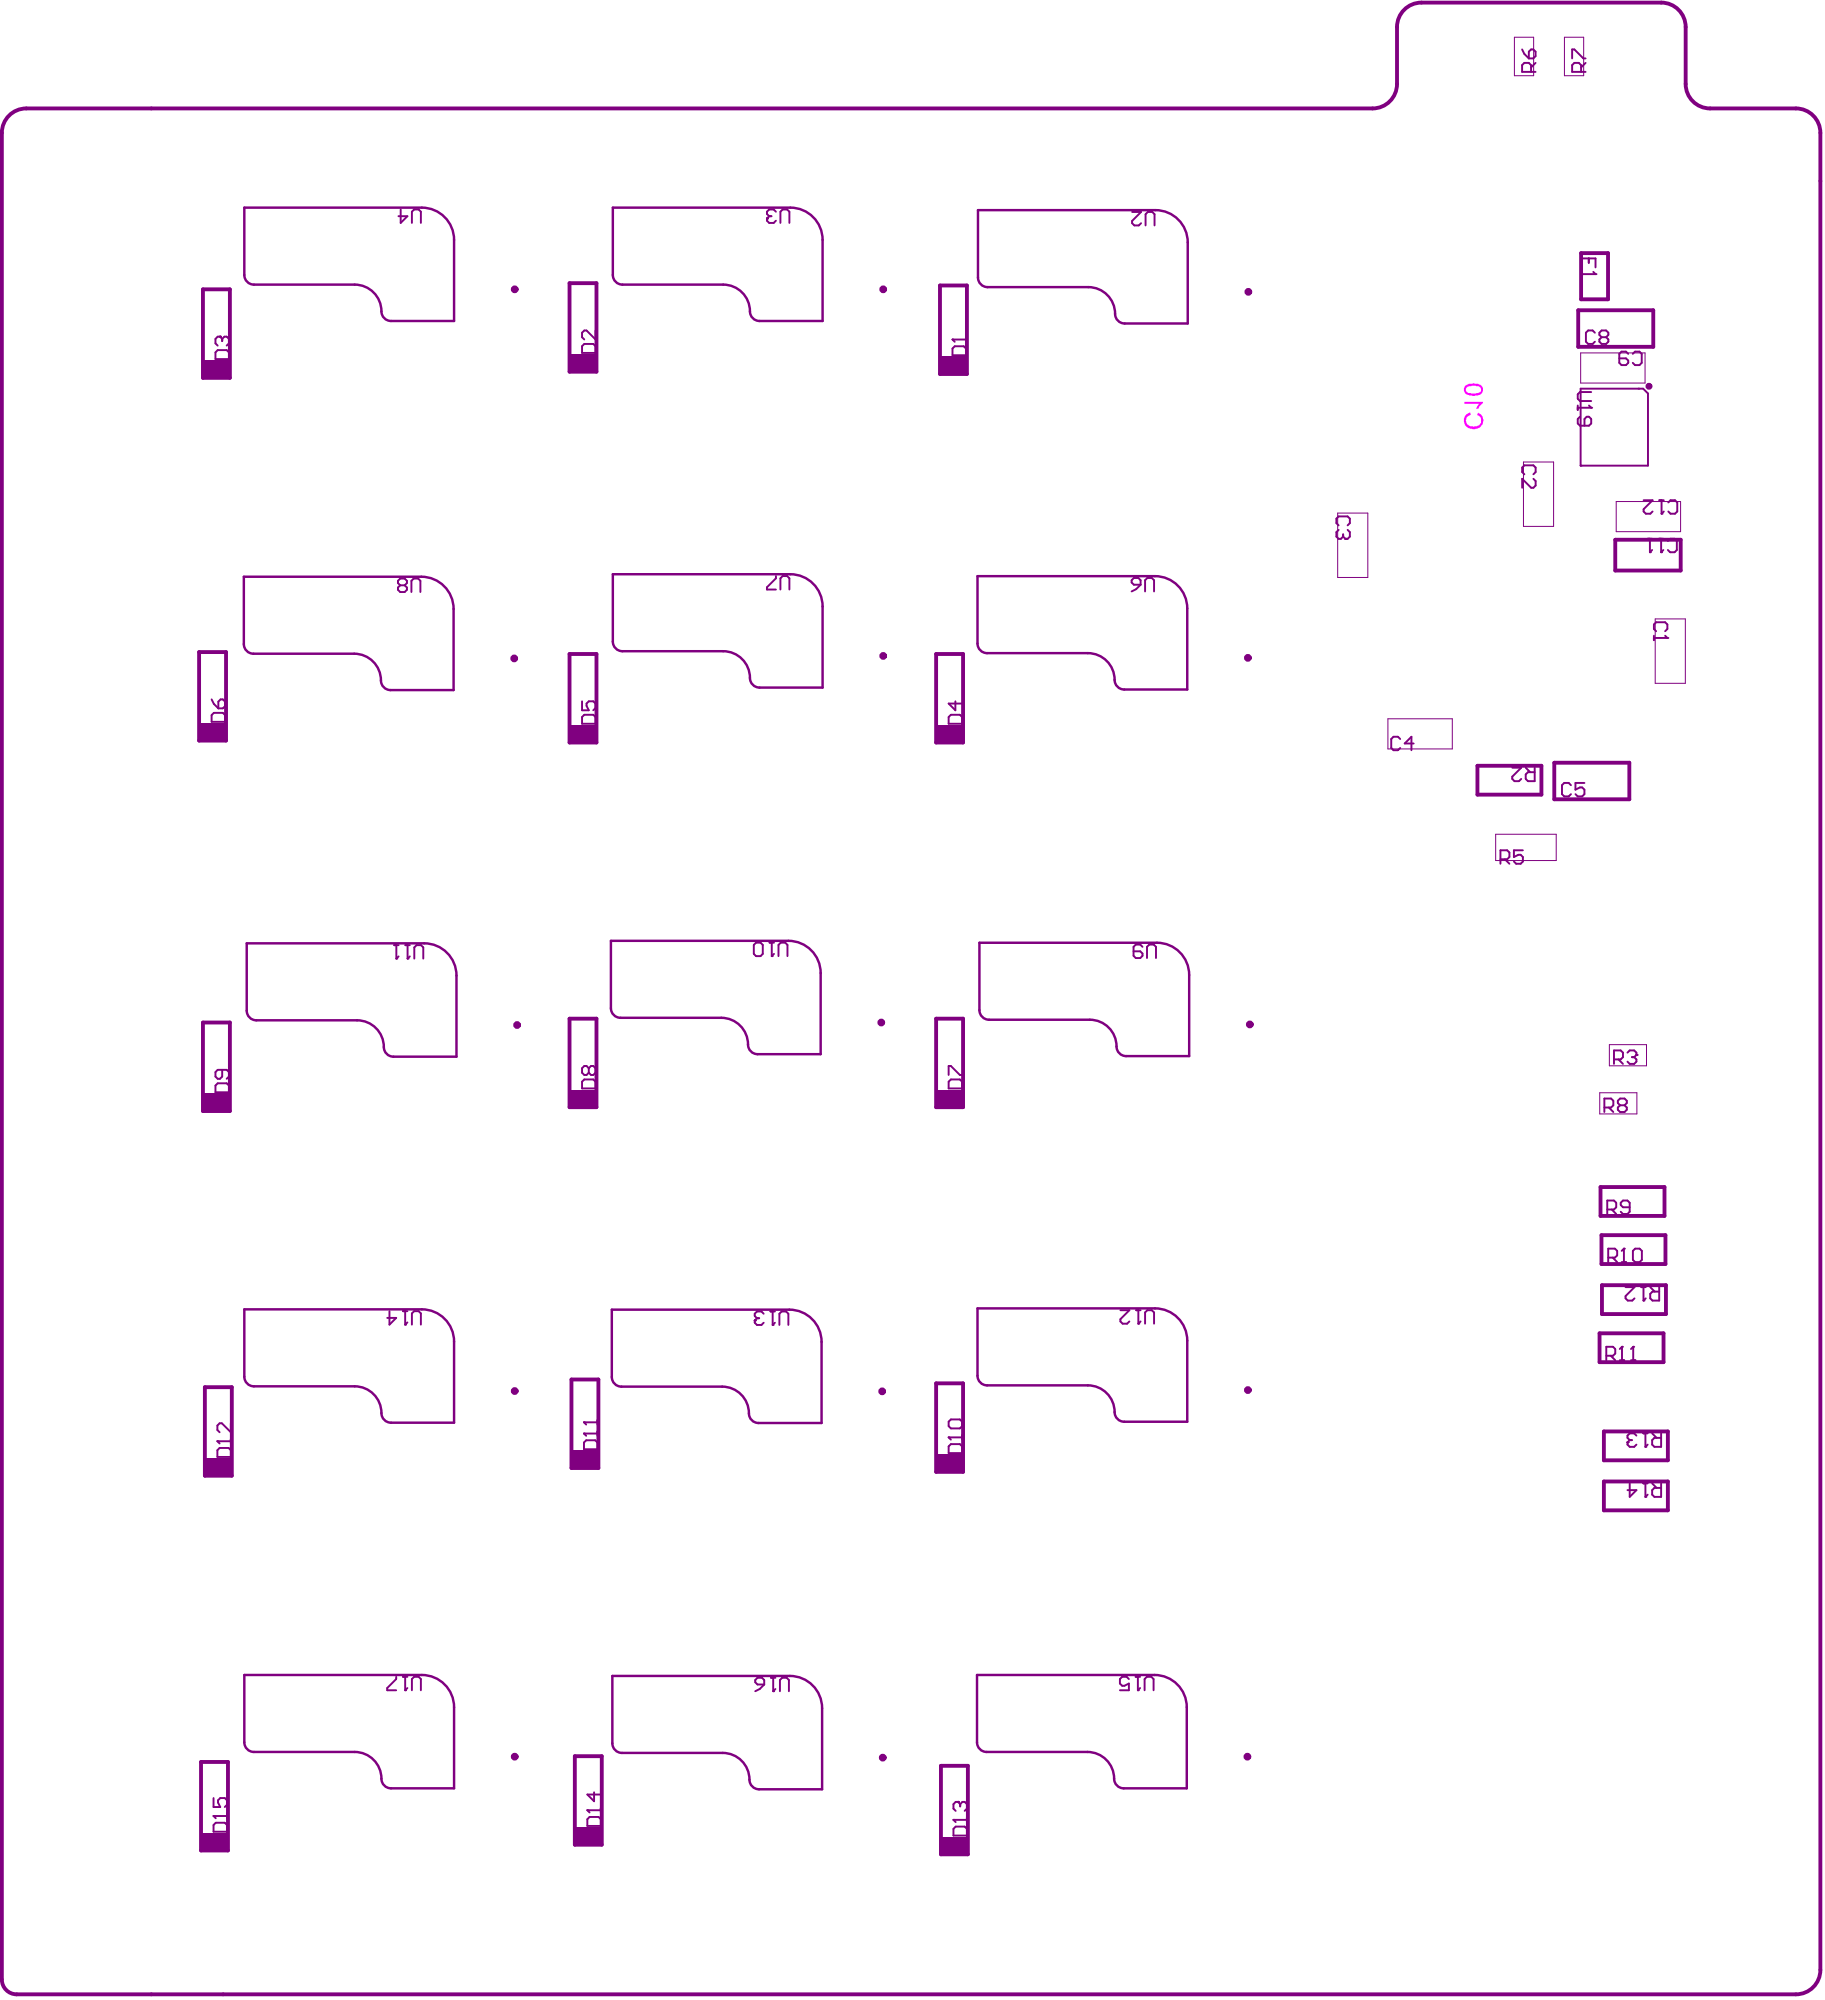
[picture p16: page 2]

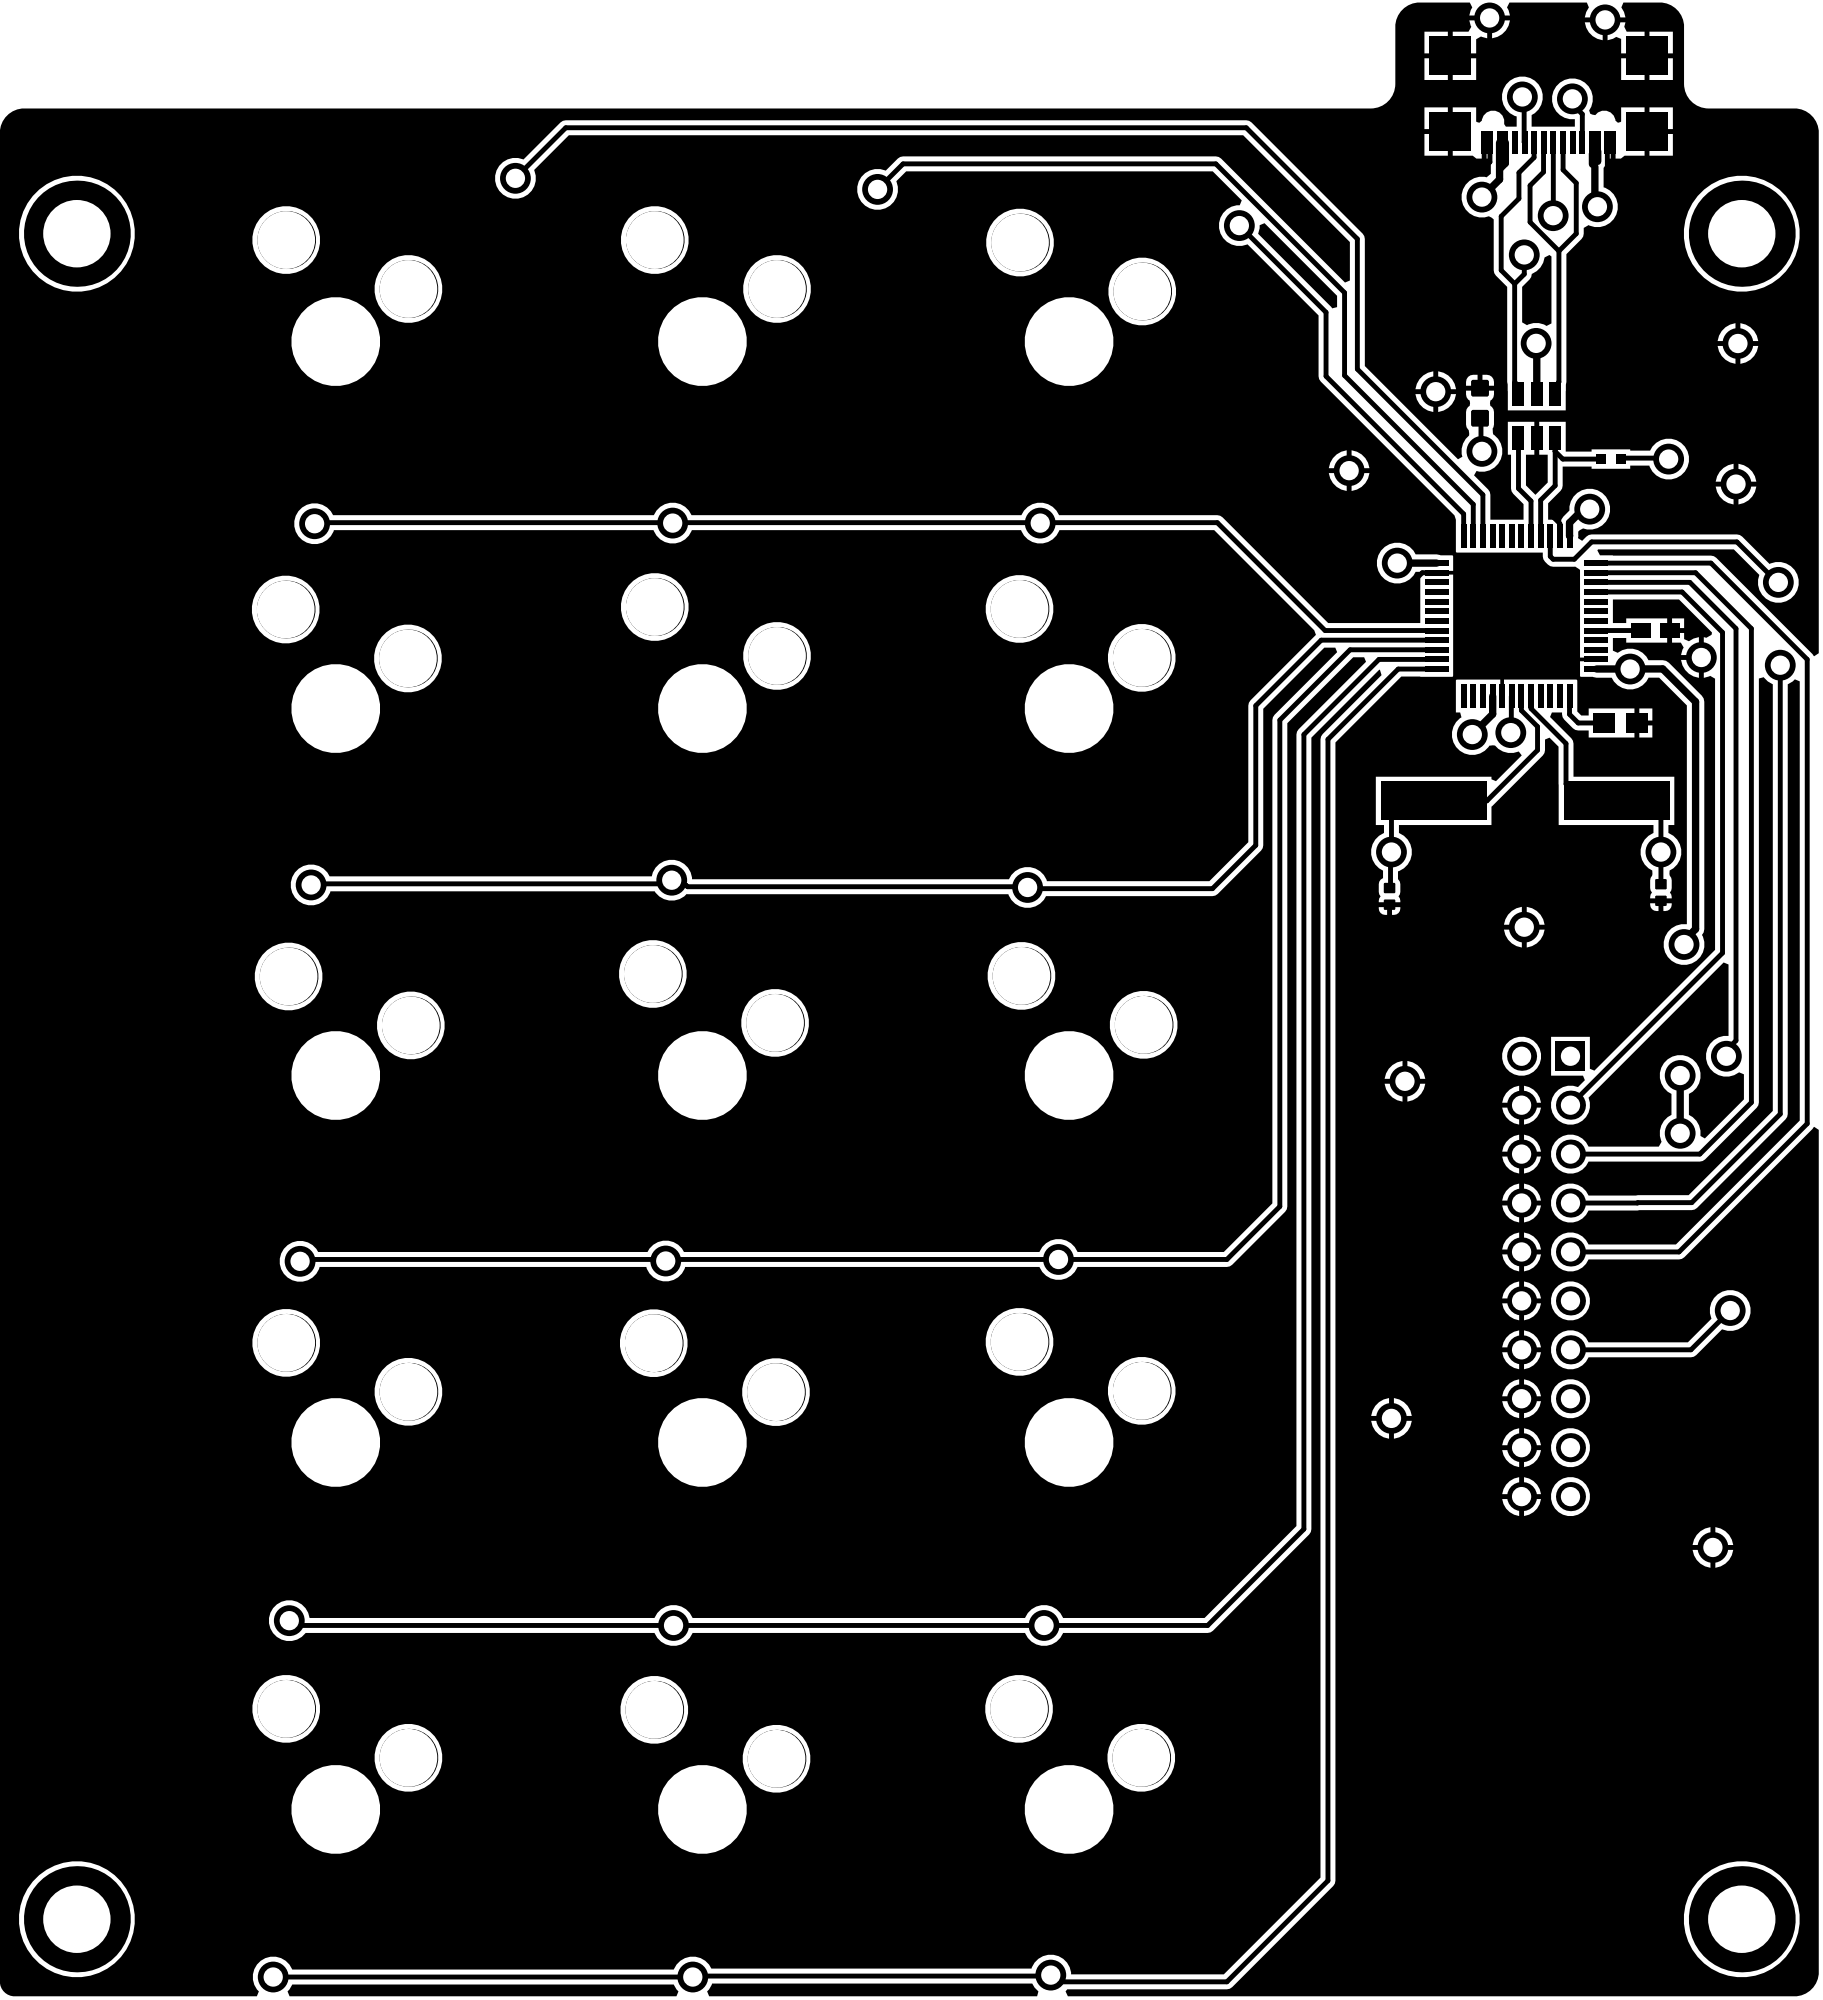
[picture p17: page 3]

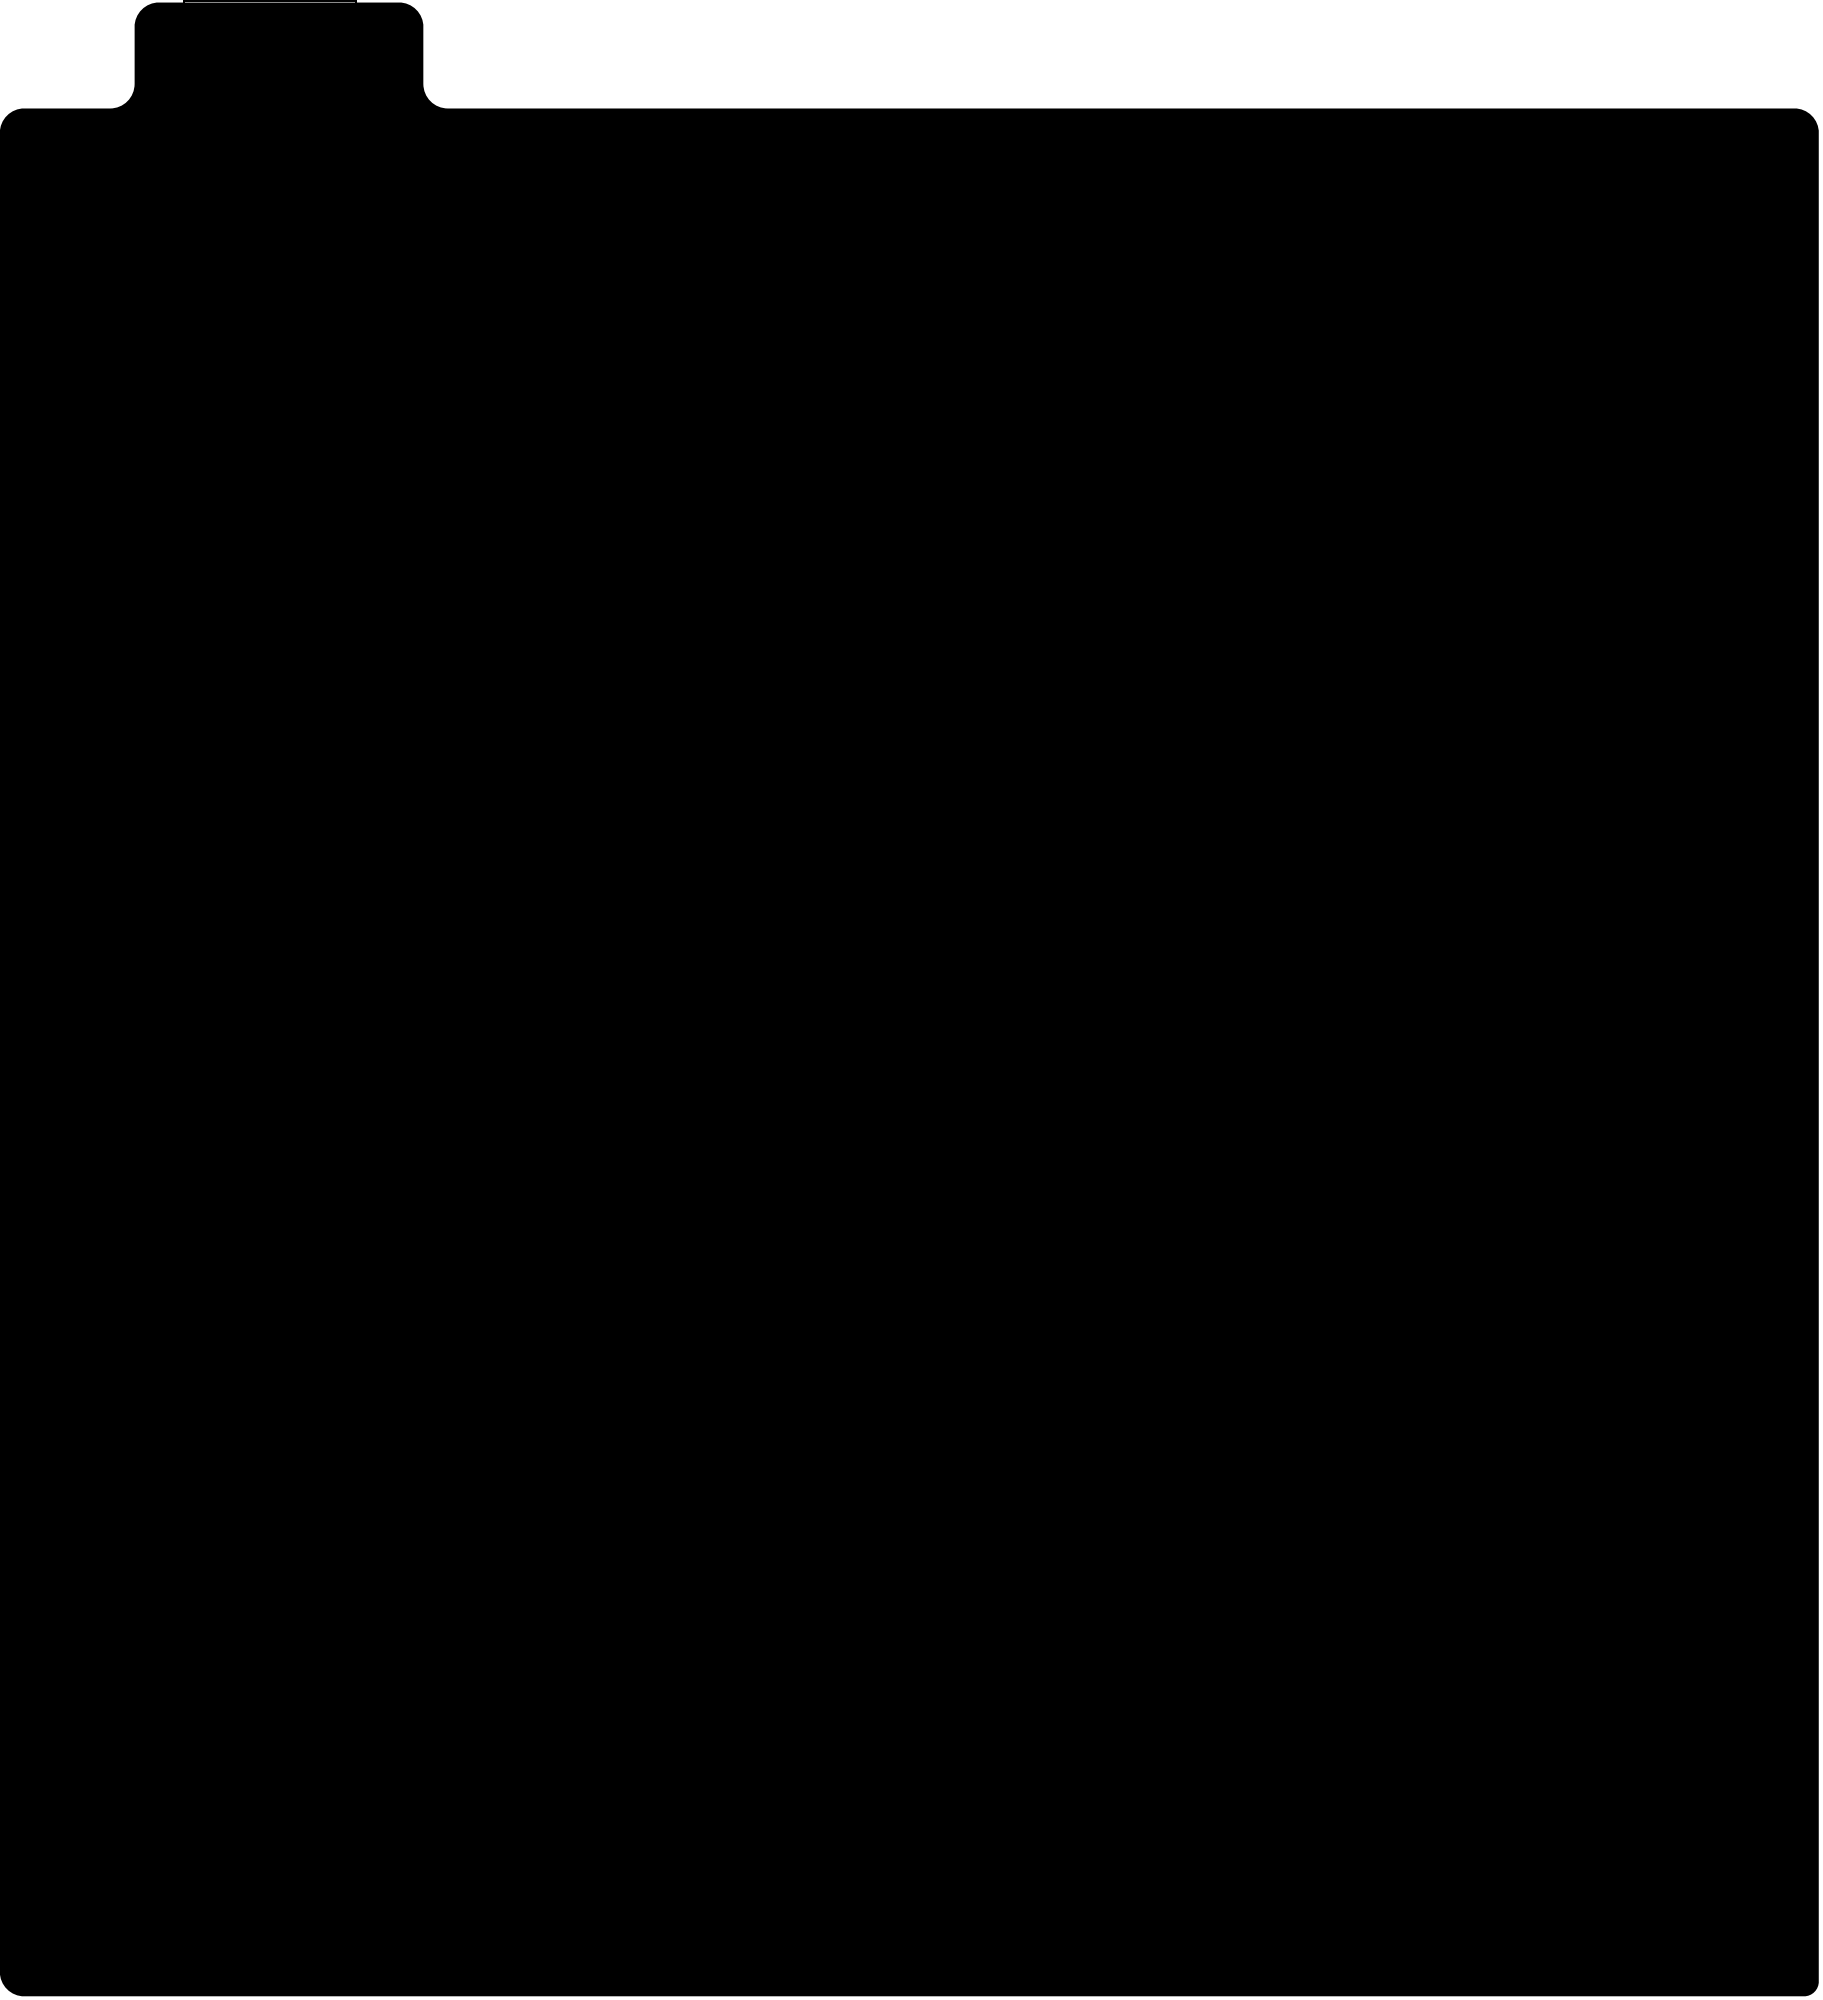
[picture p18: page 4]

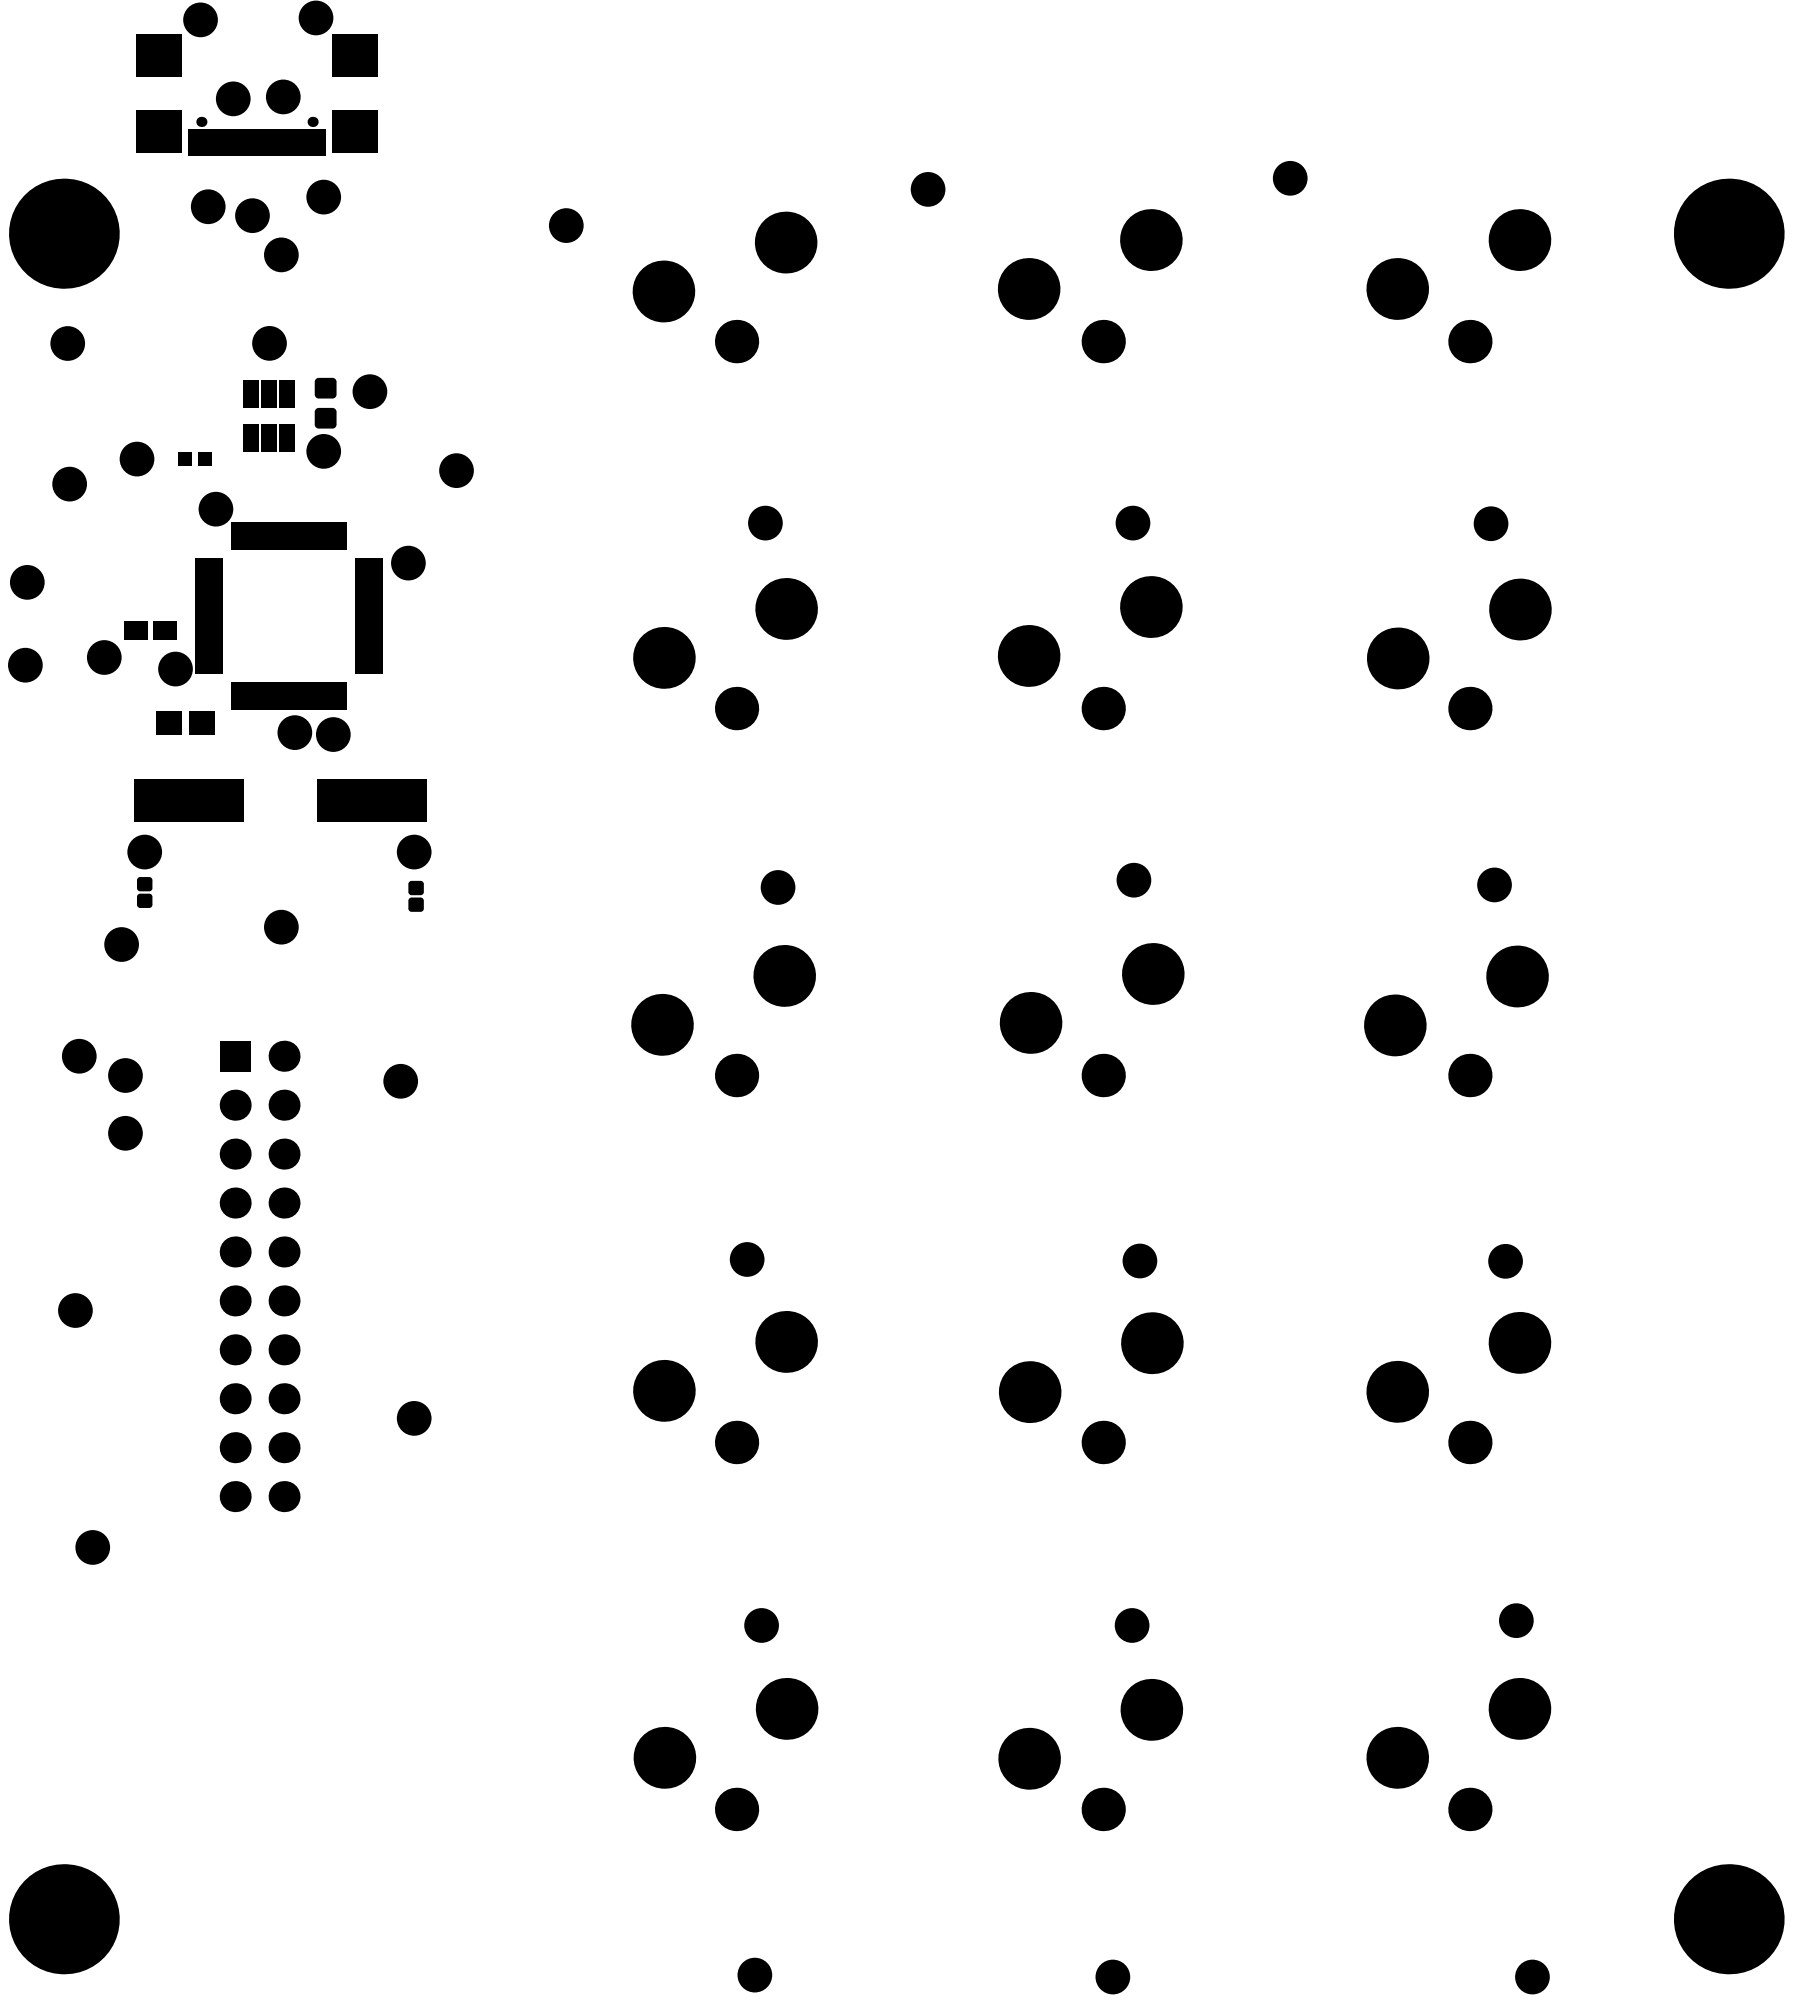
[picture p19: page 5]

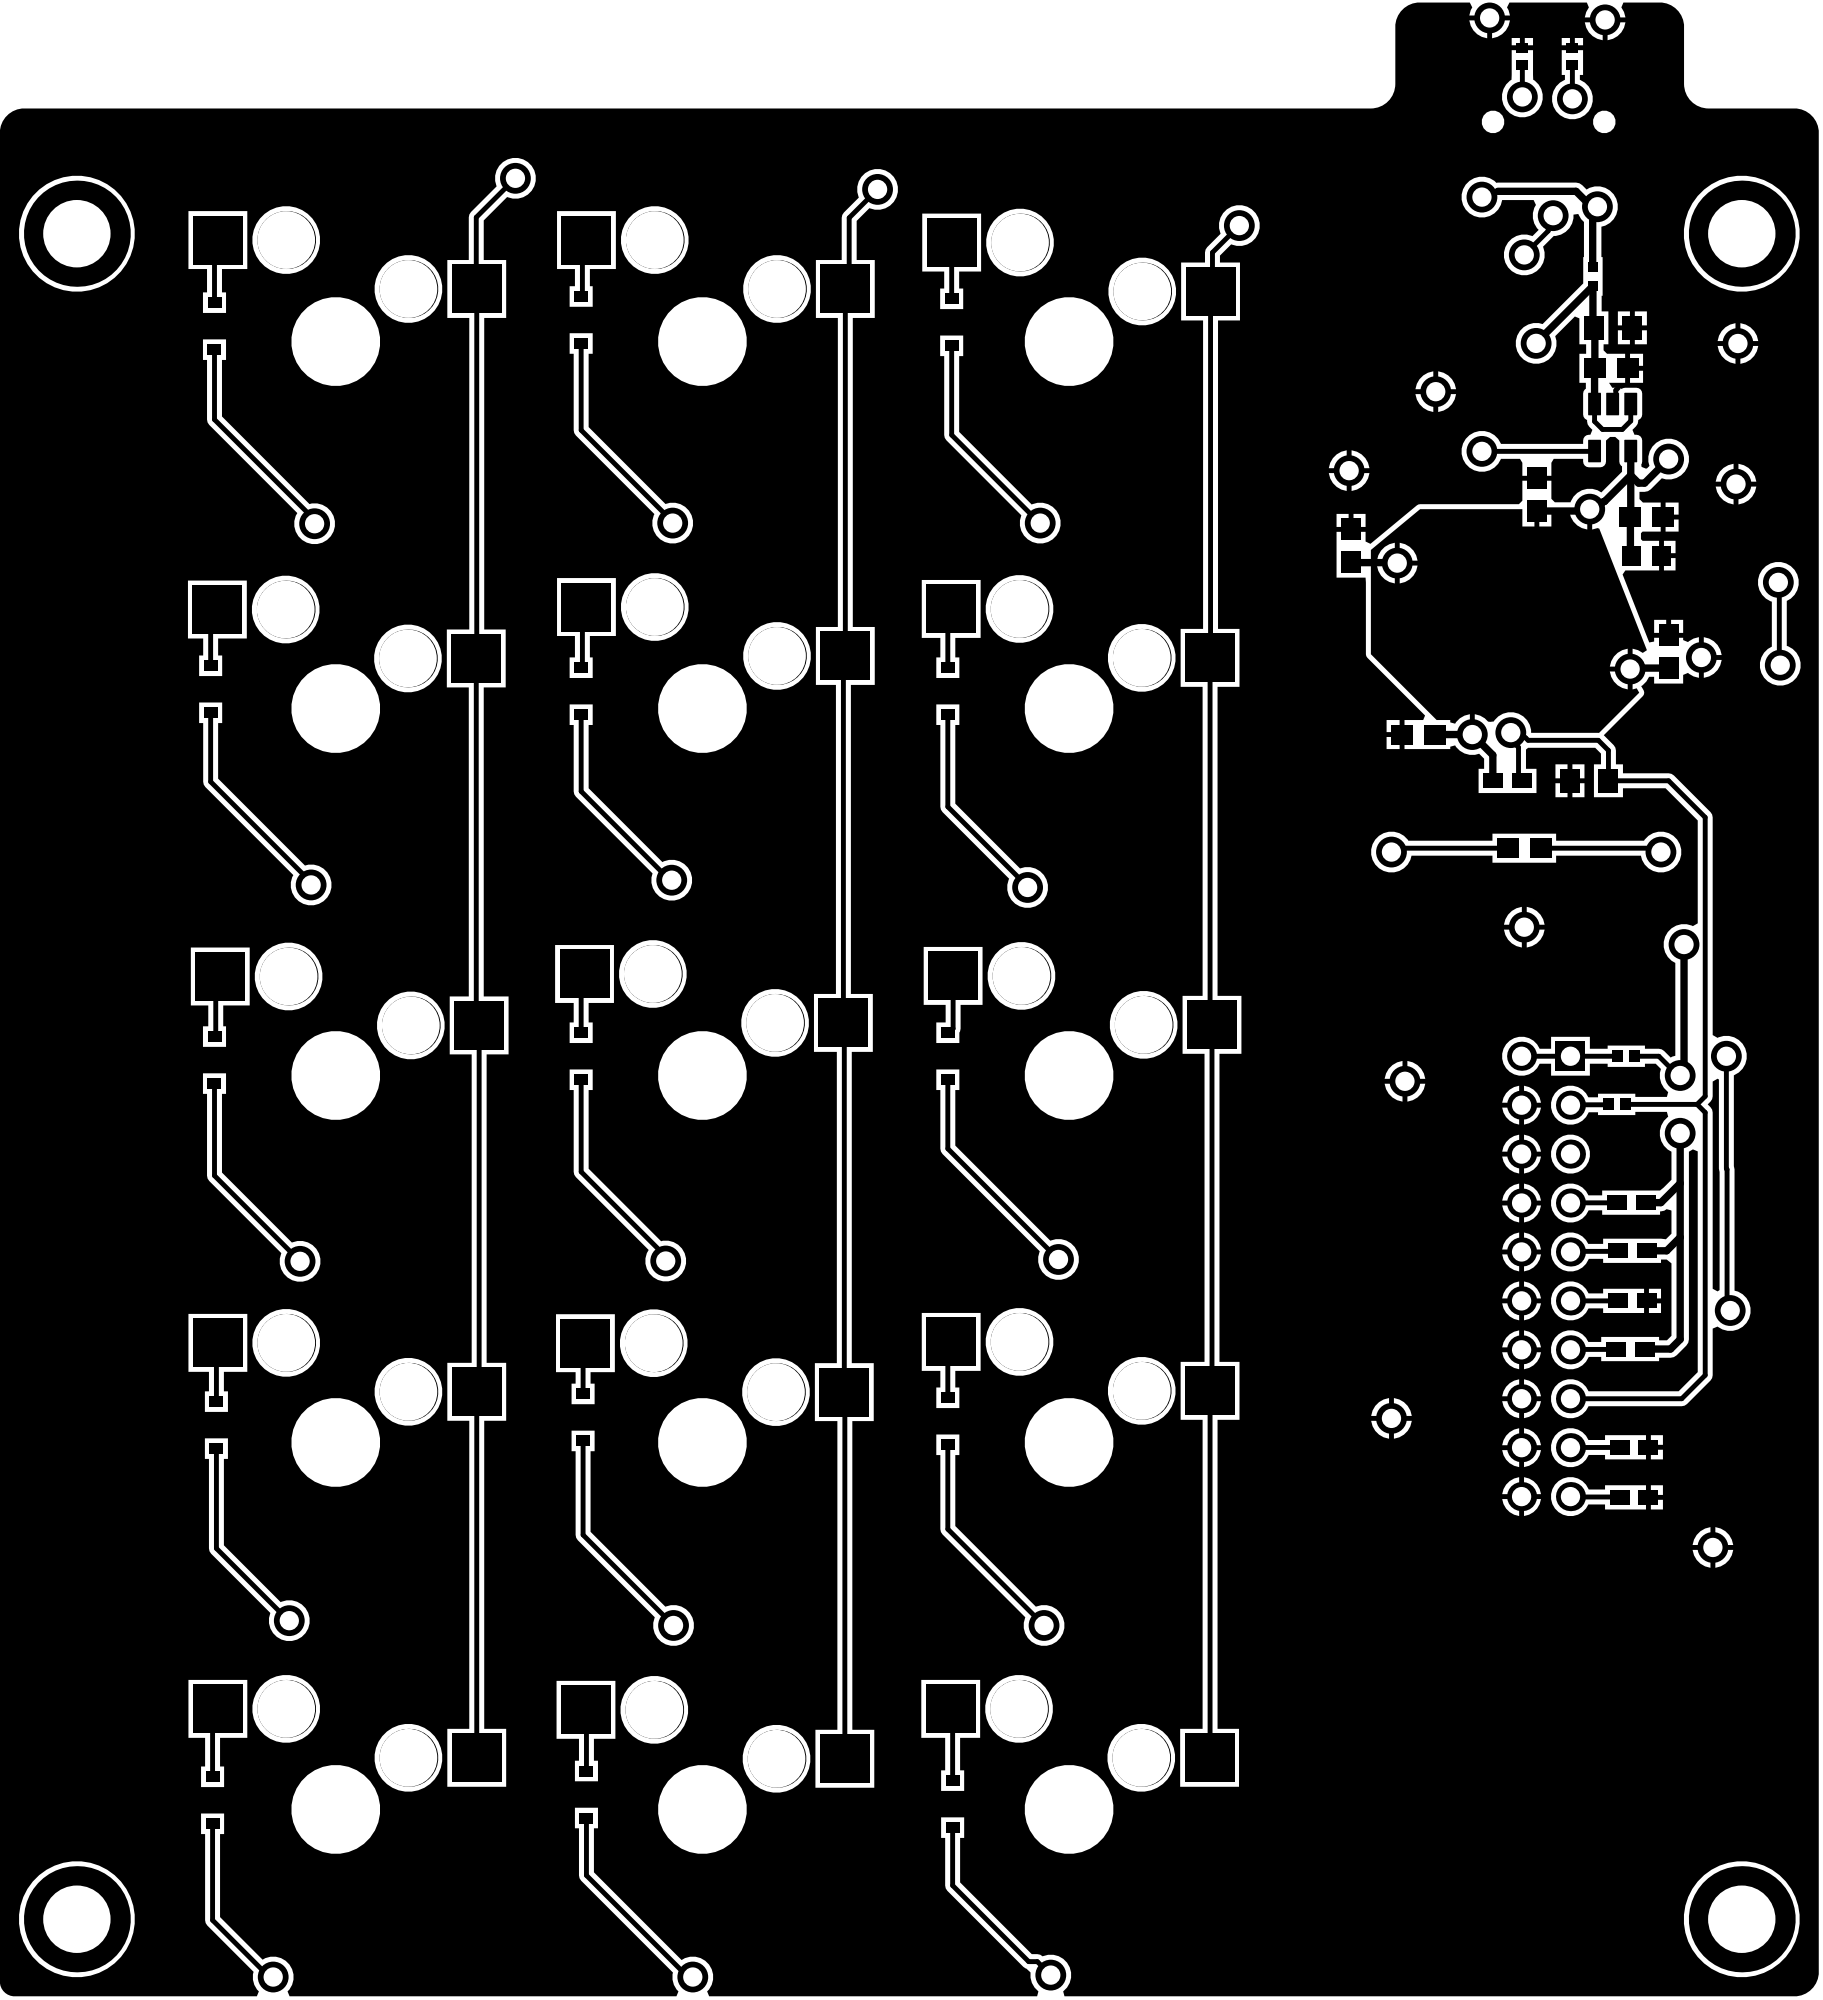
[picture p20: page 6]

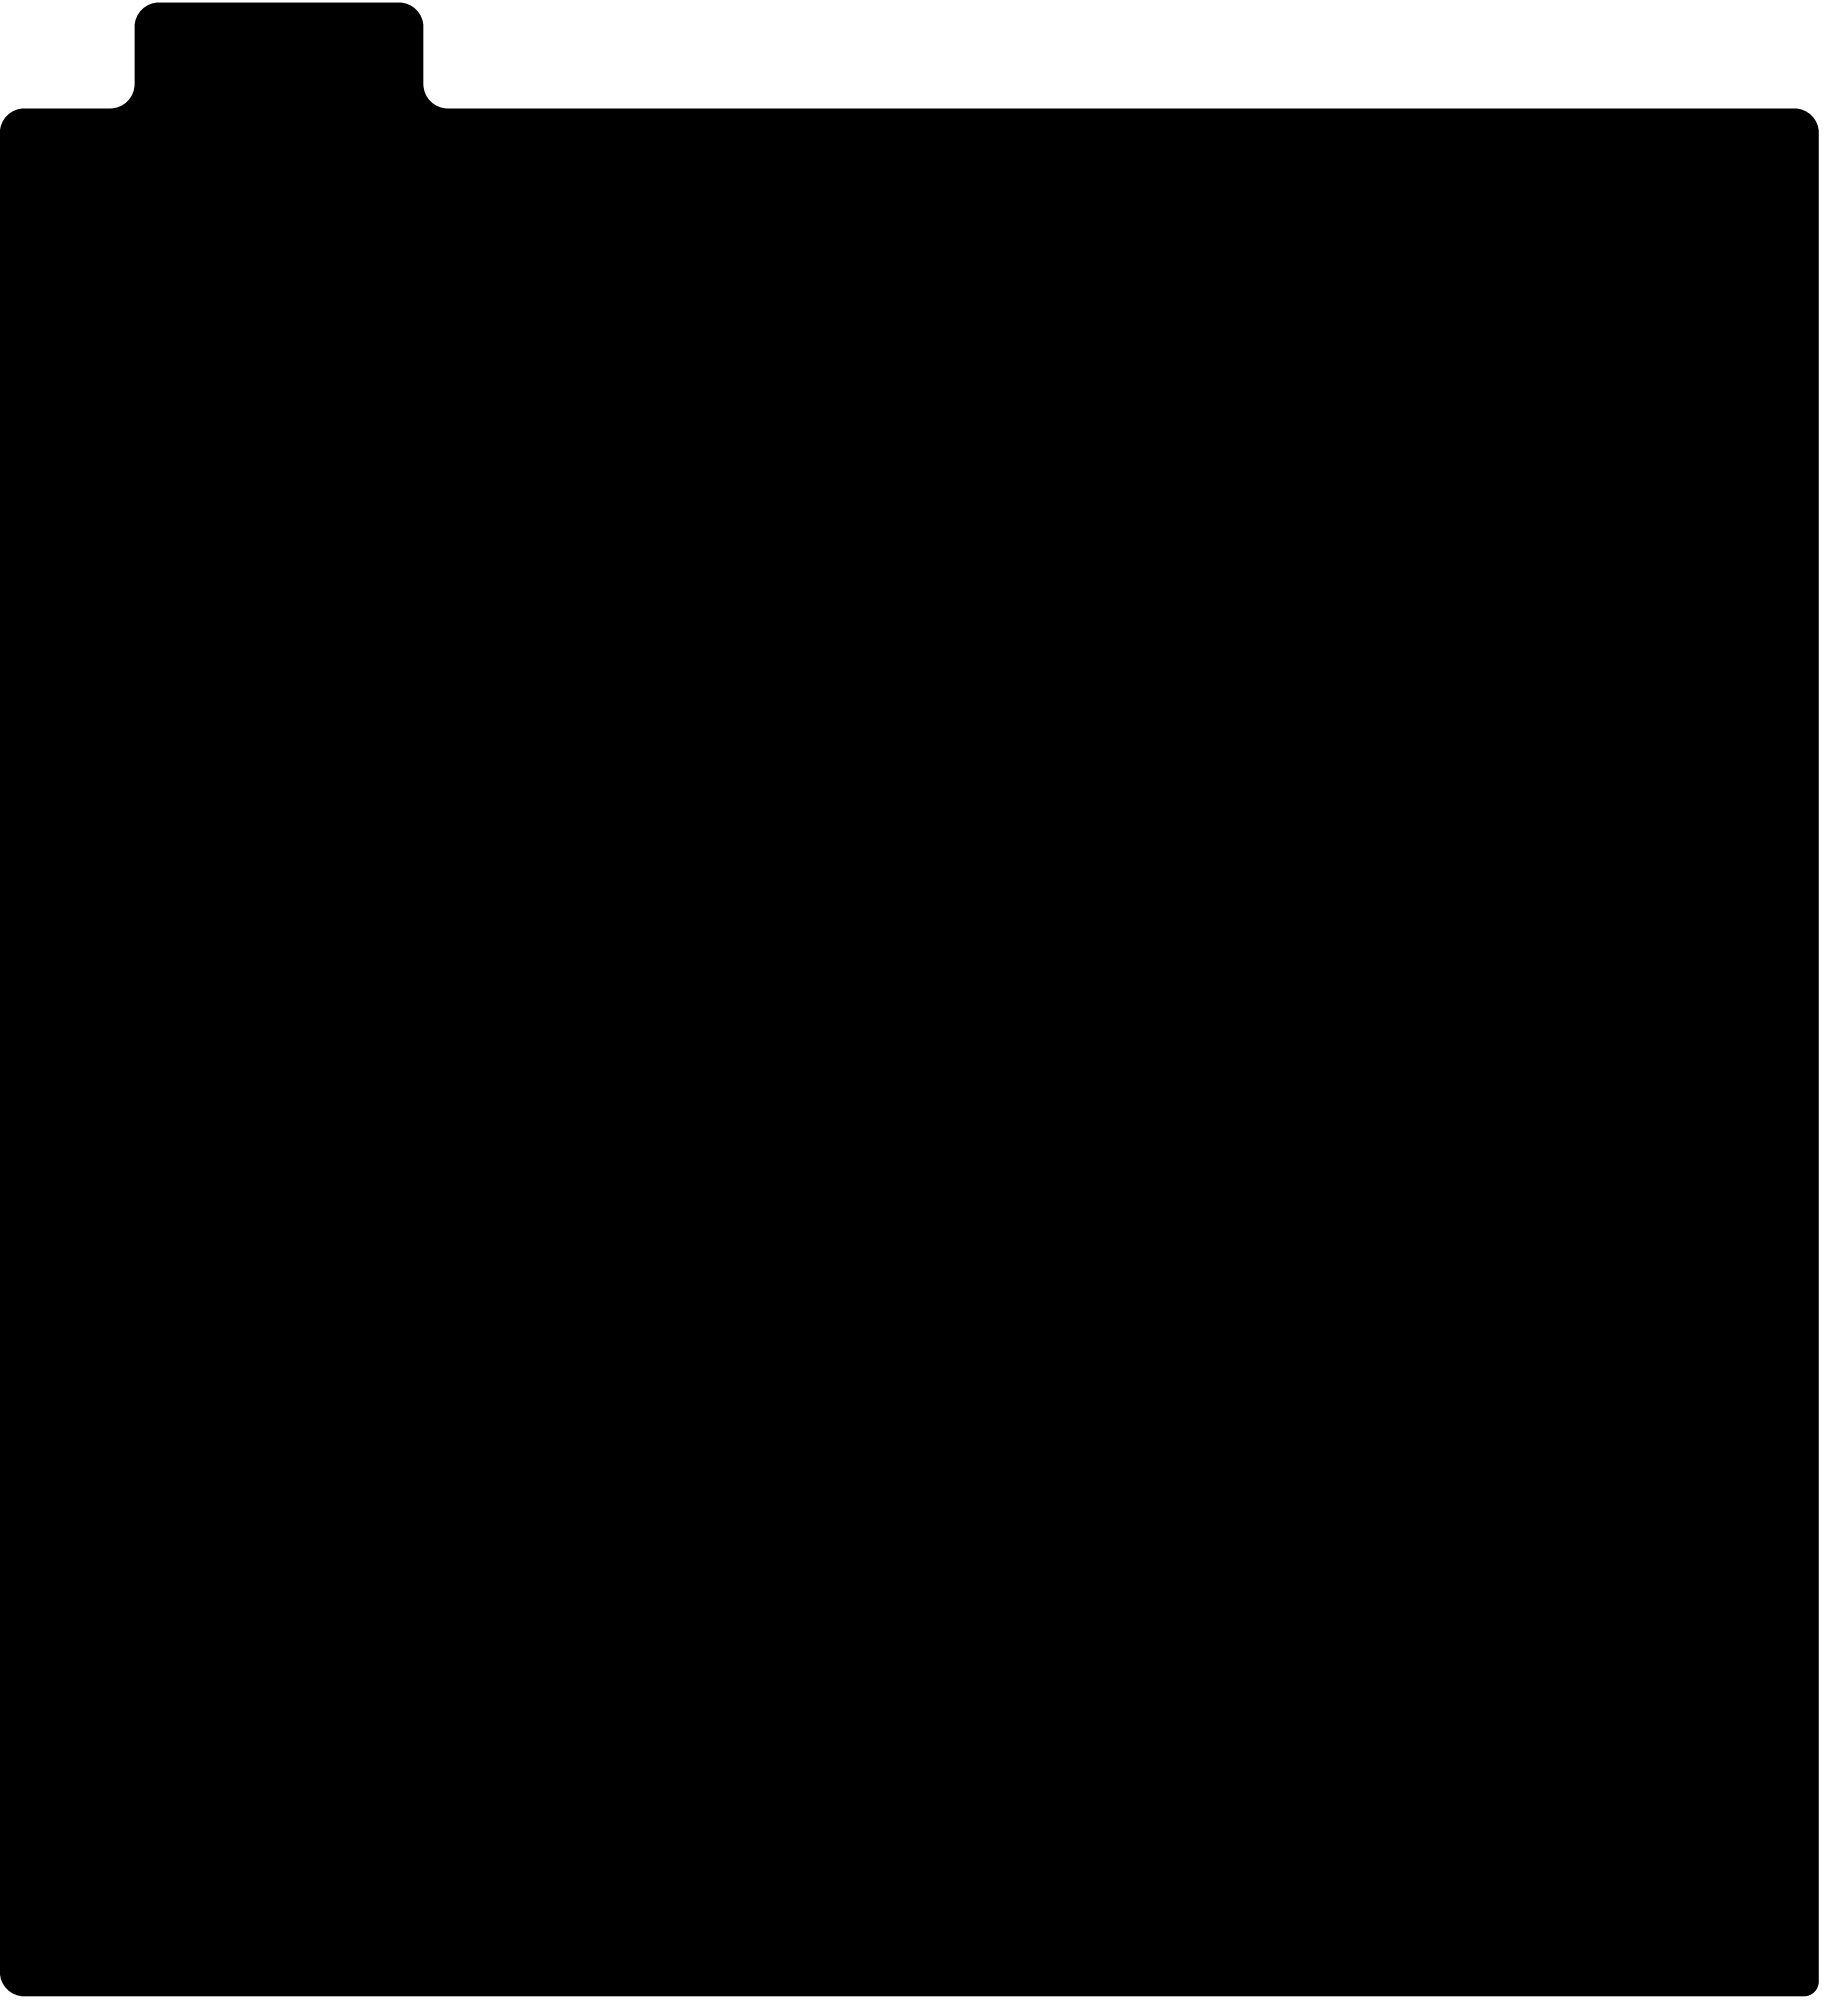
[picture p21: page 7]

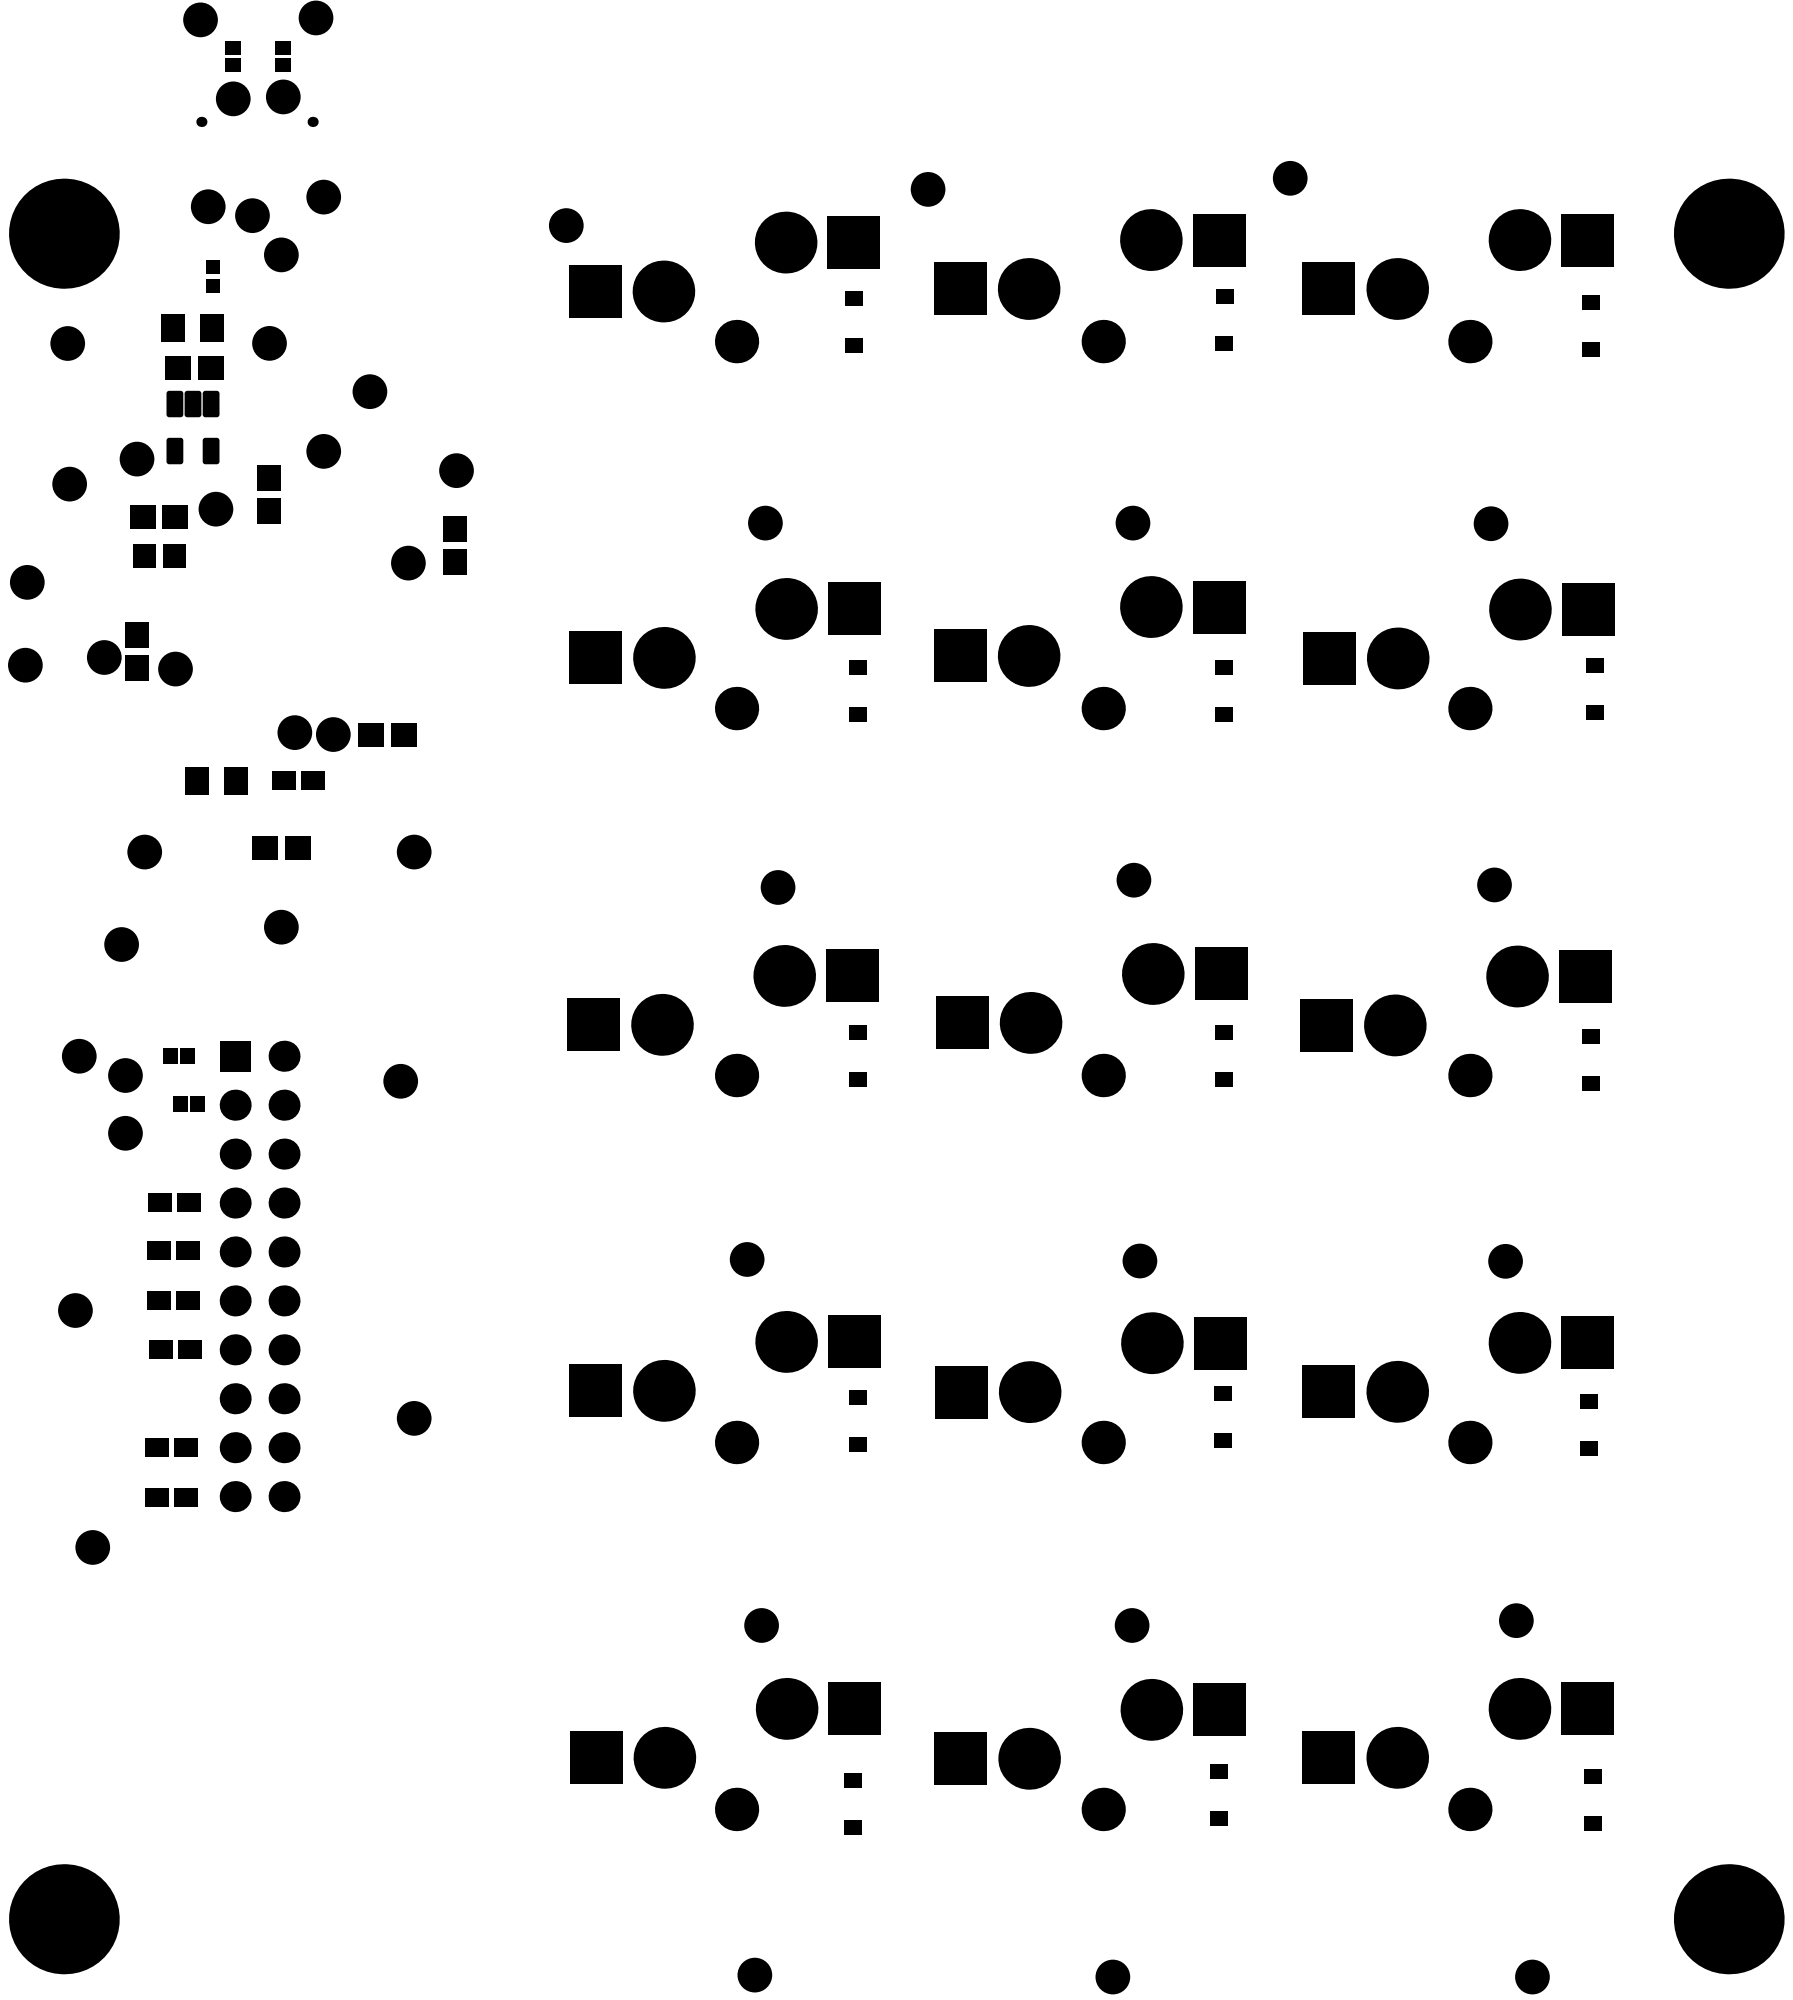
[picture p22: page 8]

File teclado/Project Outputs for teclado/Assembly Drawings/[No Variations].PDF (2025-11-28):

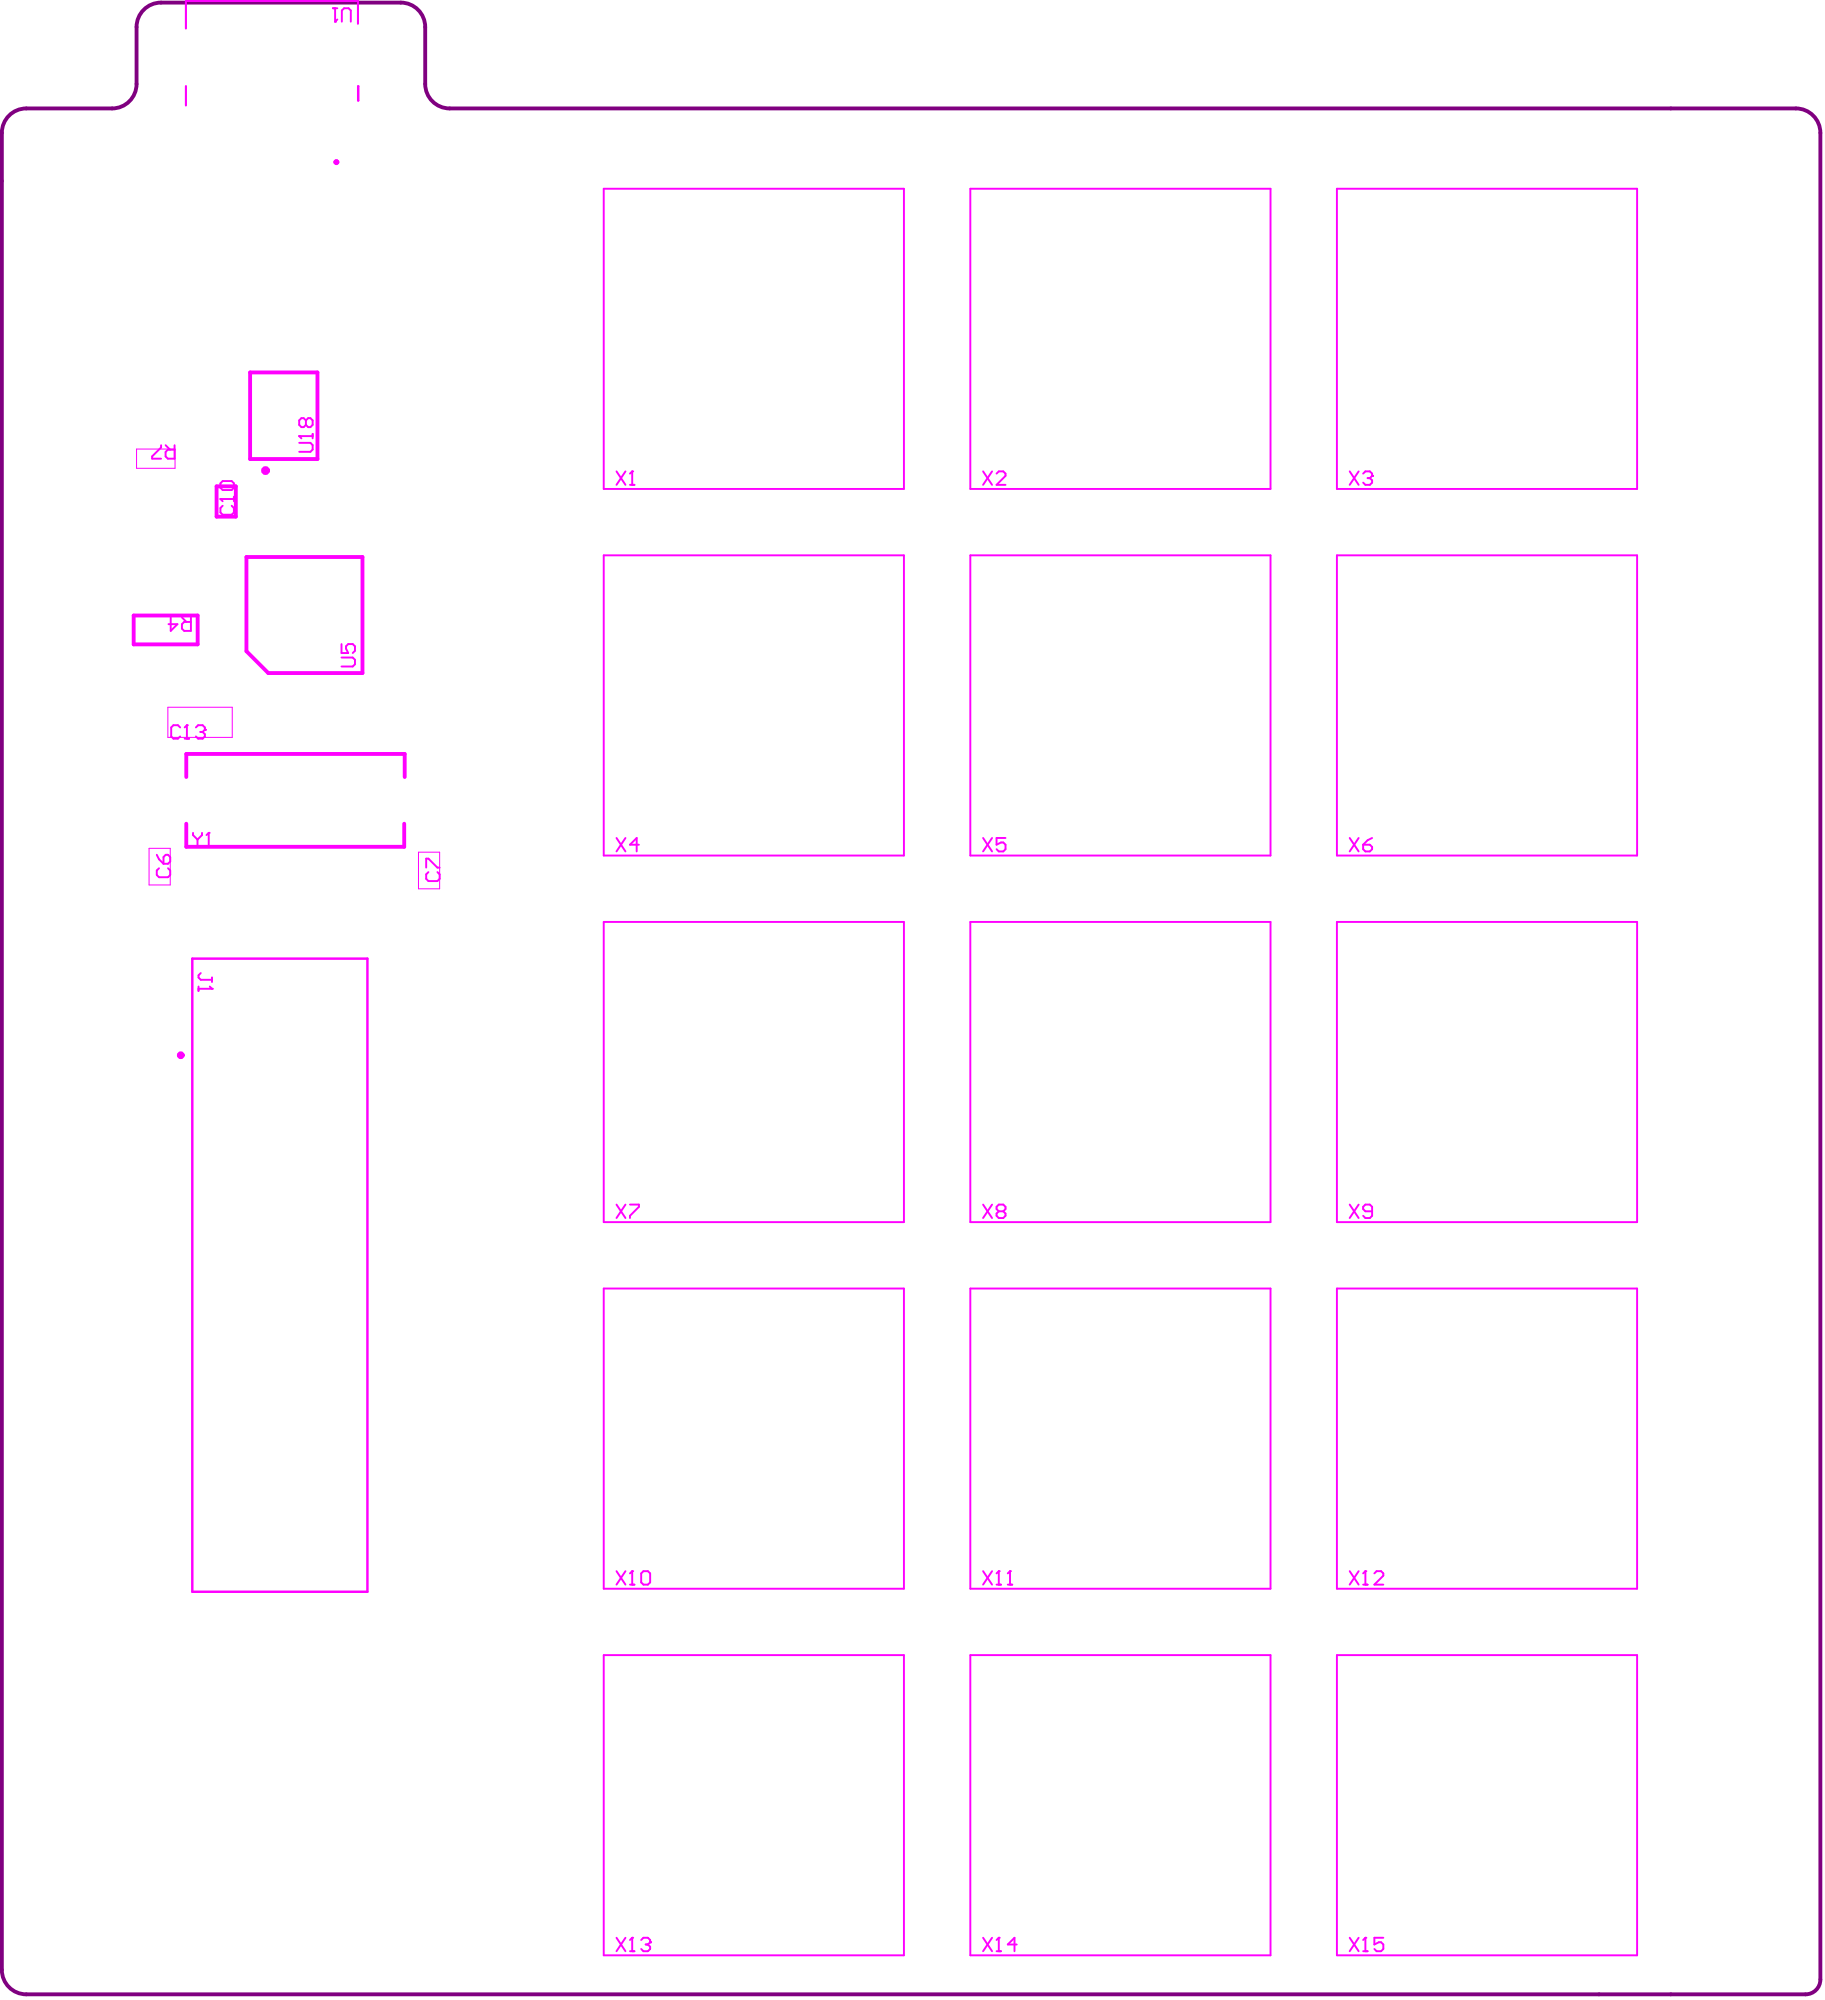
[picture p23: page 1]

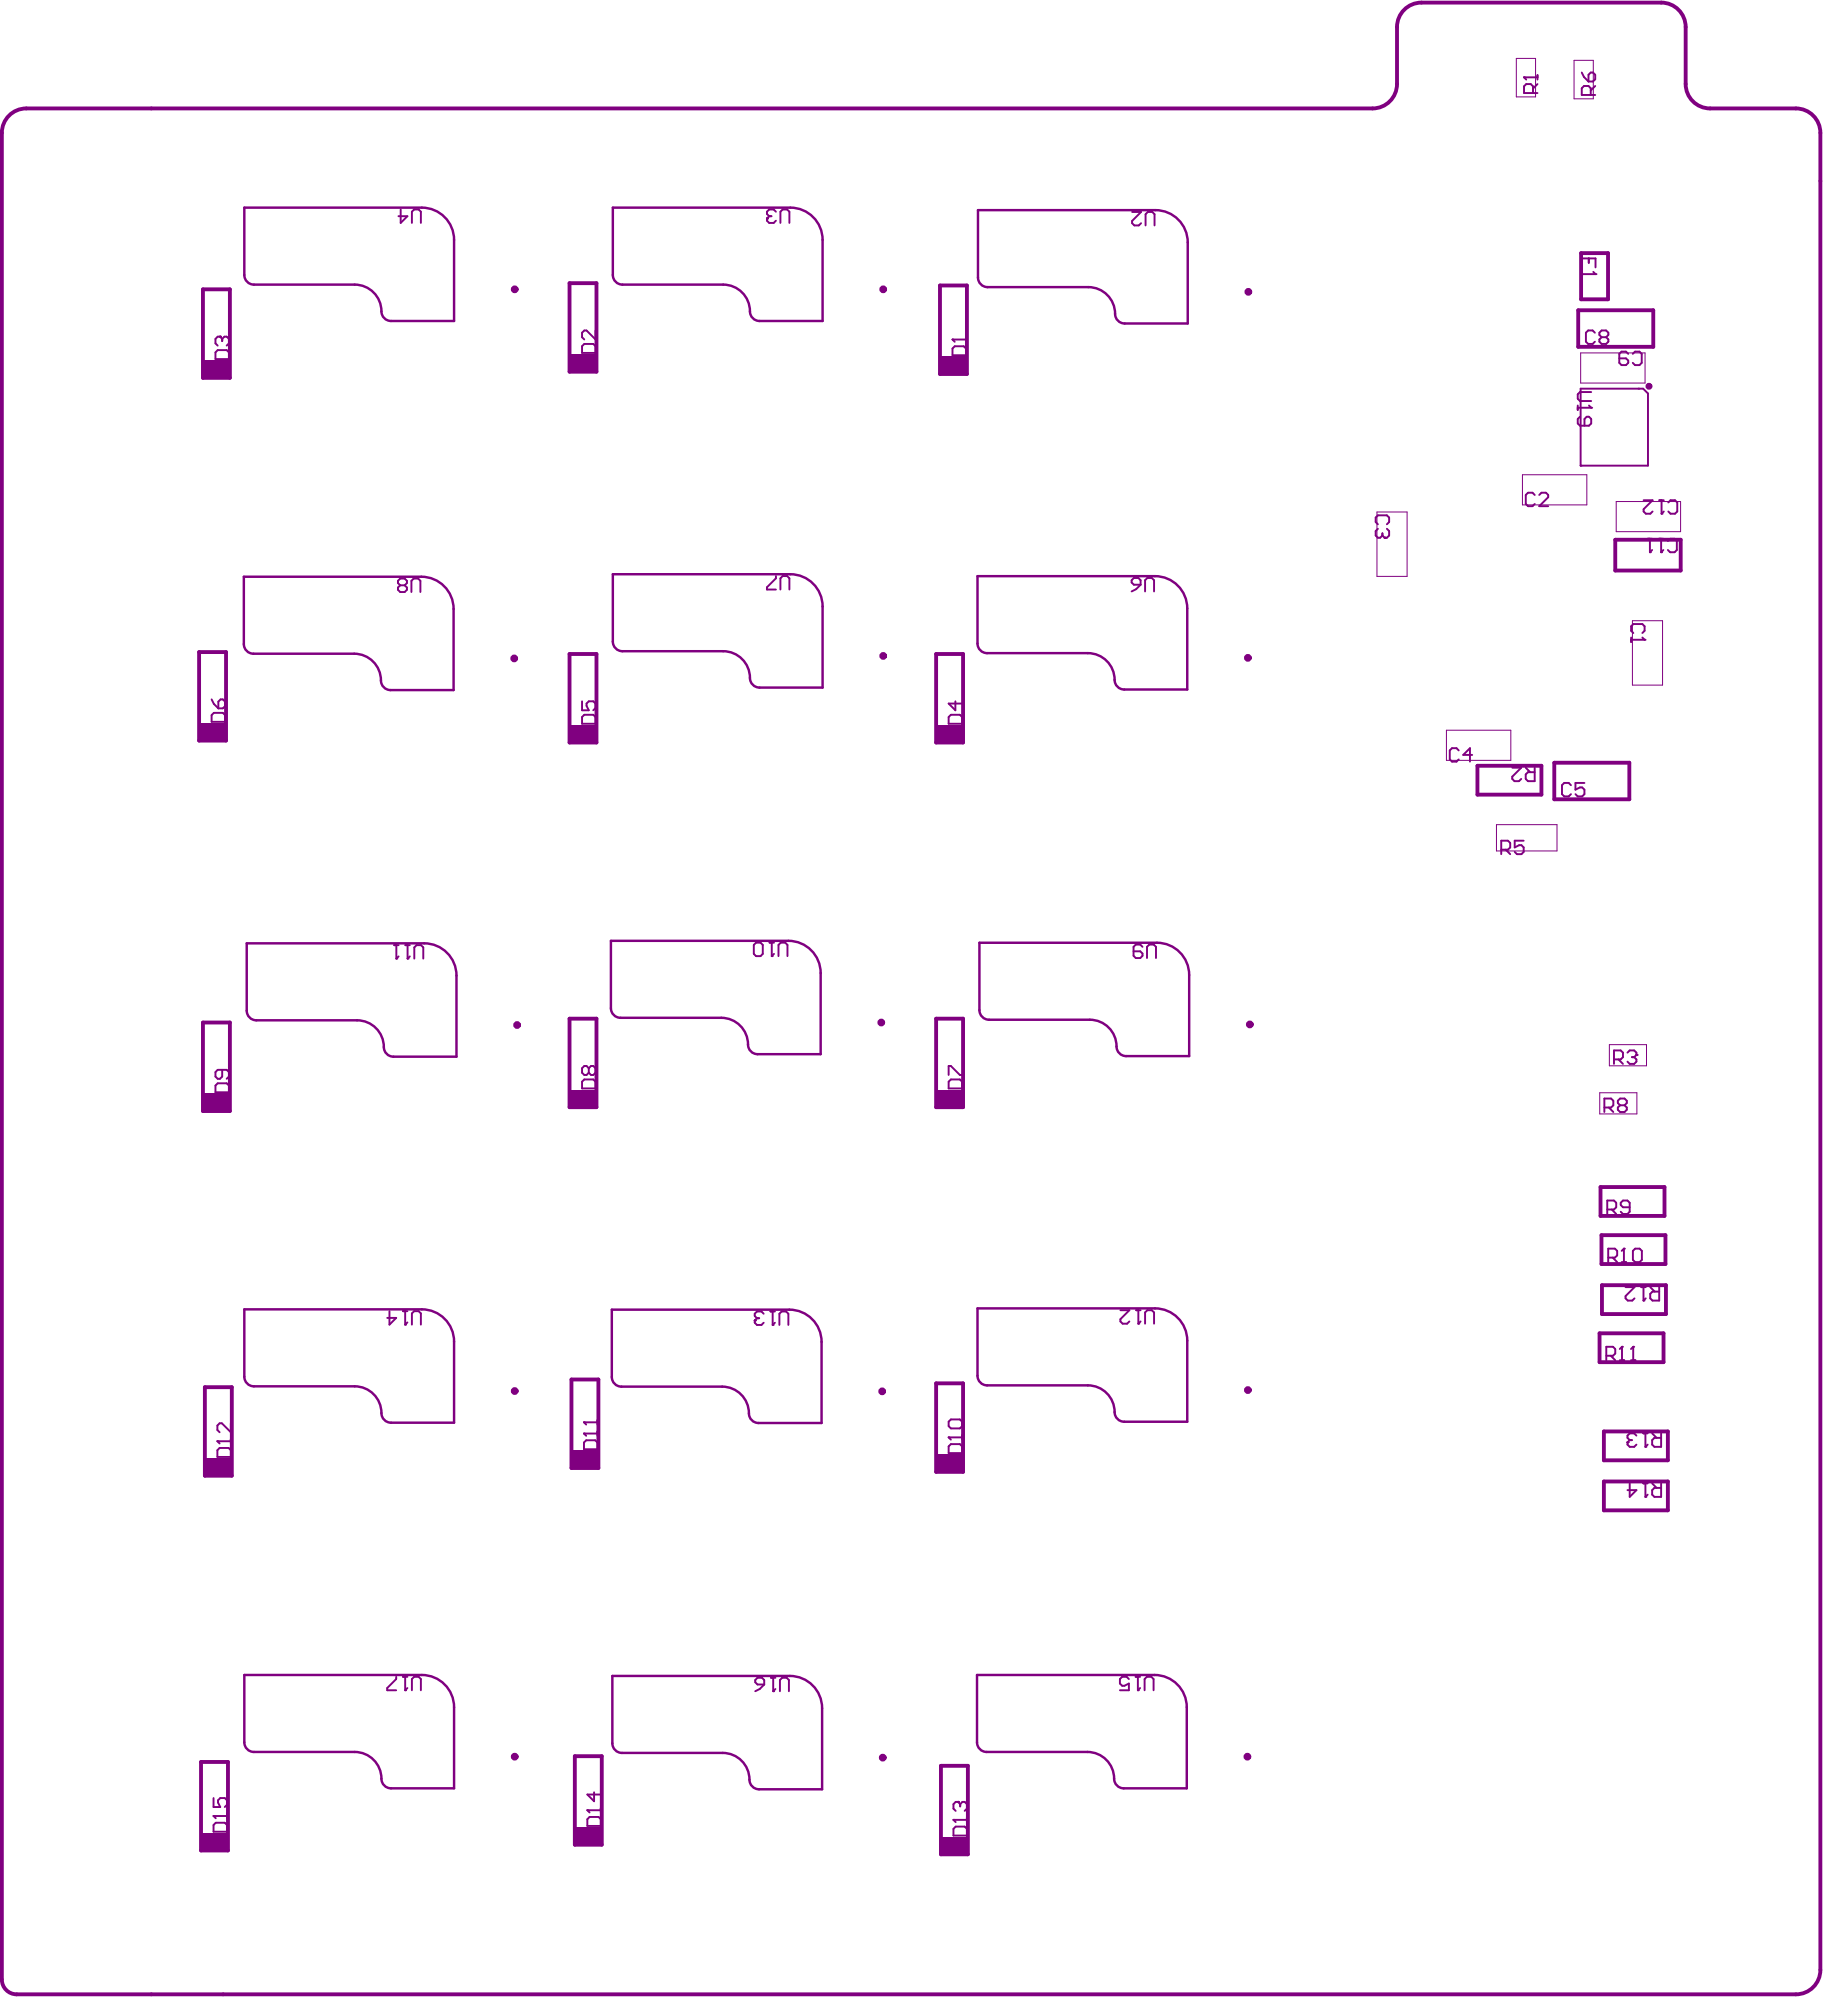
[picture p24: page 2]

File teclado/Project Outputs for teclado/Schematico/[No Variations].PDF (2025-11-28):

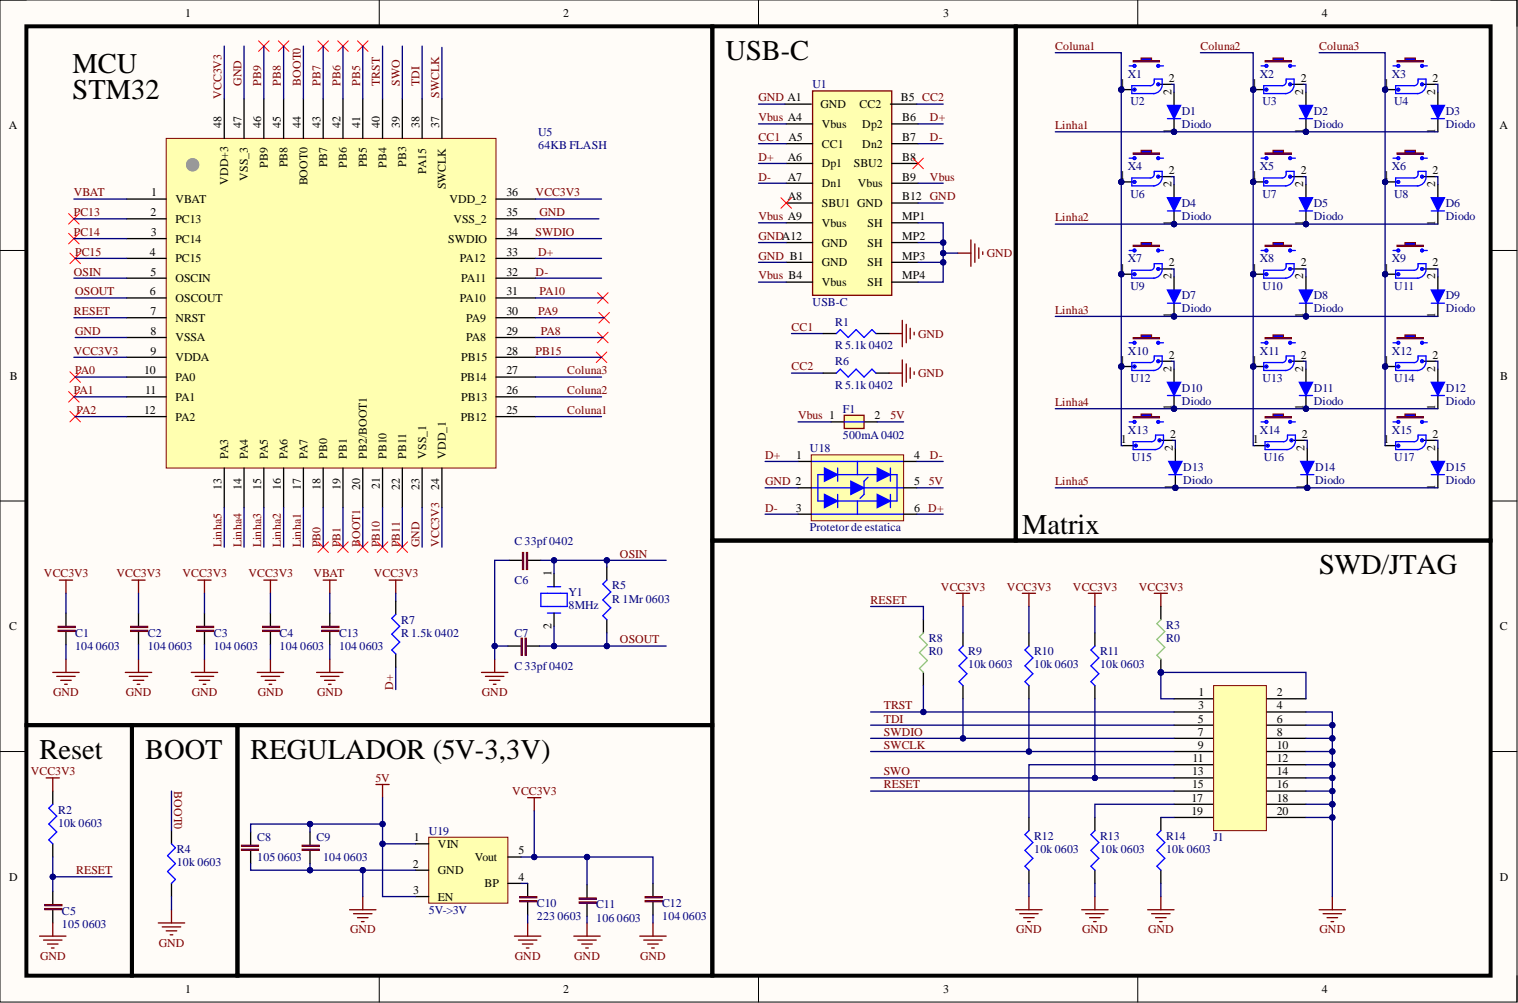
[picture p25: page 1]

1 1 | 1 2
1 3 | 1 4

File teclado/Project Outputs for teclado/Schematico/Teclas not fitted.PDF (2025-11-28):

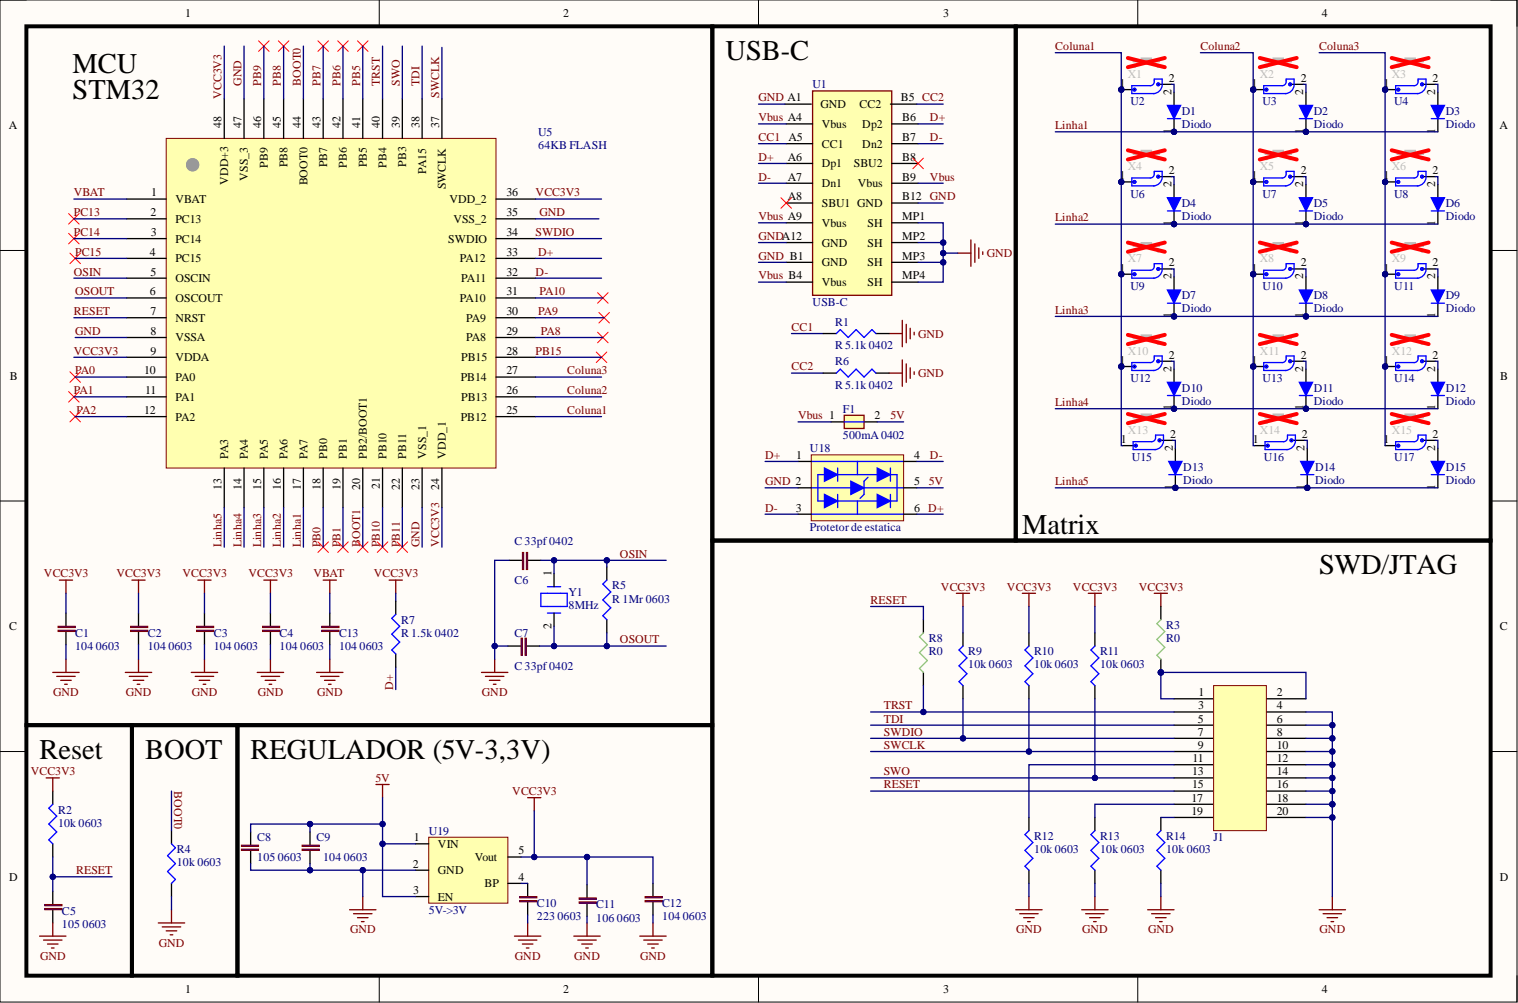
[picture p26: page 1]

1 1 | 1 2
1 3 | 1 4








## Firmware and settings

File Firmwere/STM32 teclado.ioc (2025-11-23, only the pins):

Mcu.UserName=STM32F103C8Tx
PA11.Signal=USB_DM
PA12.Signal=USB_DP
PA13.Signal=SYS_JTMS-SWDIO
PA14.Signal=SYS_JTCK-SWCLK
PA3.Signal=GPIO_Input
PA4.Signal=GPIO_Input
PA5.Signal=GPIO_Input
PA6.Signal=GPIO_Input
PA7.Signal=GPIO_Input
PB12.Signal=GPIO_Output
PB13.Signal=GPIO_Output
PB14.Signal=GPIO_Output
PD0-OSC_IN.Signal=RCC_OSC_IN
PD1-OSC_OUT.Signal=RCC_OSC_OUT

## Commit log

2025-11-06 Projeto
    Segue a o projeto do teclado
    [CRCW060310K0FKEA.STEP, Cap 104 0603.STEP, Diodo.STEP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]
2025-11-07 Update readme 2
    tirei o note do texto
2025-11-23 Código
    Esse código para o STM ser interpretado como um teclado pelo computador
2025-11-23 Código 2
    esse em si é o código, o ultimo commit era o projeto inteiro, esse arquivo .txt tem o que seria considerado como "código"
2025-11-27 revisao prof
    [Esqlib.SchLib, PCBtc.PcbDoc, SqTeclado.SchDoc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]
2025-11-27 Update do esquemático
    *rearranjei os blocos de componentes(isso possibilitou voltar a ser tamanhão A4 de folha)
    *adicionei um resistor de 0 ohm
    *coloquei o modelos para o conector de 20p que tava faltando
    *arrumei o circuito do clk(agora os capacitor conecta ao GND e são capacitores de 33pf)**
    **seria bom verificar se isso está certo
    [C 33pf 0402.STEP, Esqlib.SchLib, PCBlib.PcbLib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]
2025-11-28 Update da PCB
    *o conector de 20p foi colocado e roteado
    *os componentes relacionados ao conector de 20p foram roteador**
    **os 3 resistores que vão para vcc3v3, coloquei em uma trilha, porem essa é mais grossa.
    *os capacitores do cristal foram mudados
    [PCBlib.PcbLib]
2025-11-28 Novos outputs
    com a placa mudada eu gerei novamente os autputs
    [Teclas not fitted.GBL, Teclas not fitted.GBO, Teclas not fitted.GBP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]
2025-11-28 Troca de componentes sem estoque na JLCPCB
    Os resistores de 1.5k e 5.1k não tinha estoque na JLCPCB então foram trocados por outros que tem
    [Esqlib.SchLib, PCBlib.PcbLib, R 1.5k 0402.step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]
2025-11-28 Novos outputs
    de novo gerando os outputs por conta de mudanças na placa
    [SqTeclado.SchDoc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]
2025-11-28 atualiza 1
    update do output
    [SqTeclado.SchDoc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]
2025-11-29 Problemas corrigidos
    acho que eu arrumei os problemas que eu estava tendo agora o site aceita os arquivos e posso fazer a cotação
    *nota o site coloca os componentes errados em alguns, precisa arrumar manualmente, mas tirando isso ta ok eu acho
    [Teclas not fitted.GBL, Teclas not fitted.GBO, Teclas not fitted.GBP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]
2025-11-29 Update final para pedir a placa
    O C10 não tinha na JLC ai coloquei outro
    [Esqlib.SchLib, PCBlib.PcbLib, SqTeclado.SchDoc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]
2025-11-29 Update 2
    agora ta tudo que precisa para pedir a placa, mudie so uma escrita da pcb
    a placa ja ta no carrinho da jlcpcb
    [Teclas not fitted.GBL, Teclas not fitted.GBO, Teclas not fitted.GBP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]
2025-12-11 Relatorio+dependencias
    -esse commit inclui o relatório final, a maioria das mudanças é para seguir o que o relatório descreve
    -foi adicionado uma pasta com os modelos 3d para a impressão e um arquivo .step que contem o projeto em 3d.
    [CaixaTeclado.stl, Keycap.stl, TampaTeclado.stl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]
2025-12-11 Update de placa+fix relatorio
    -a placa agora tem vias maiores
    -os outputs relevantes as mudanças foram gerados novamente
    -corrigi um erro no relatório
    [[No Variations].csv, teclado.PrjPcb]
2025-12-16 Protetor de estatica da USB corrigido
    [Esqlib.SchLib, SqTeclado.SchDoc, teclado.PrjPcb]
2025-12-16 update
    -protetor de estatica
    -roteamento placa
    [SqTeclado.SchDoc]
2025-12-16 circuito do cristal revisado
    [SqTeclado.SchDoc]
2025-12-16 PCB/esquemático update
    Esquematico:
    -cap de 27pf 0603 colocado
    -todos components que antes não eram 0603, agora são
    PCB:
    -reorganiza os componentes mudados no esq
    -tira a borda extra da pcb
    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
    [Esqlib.SchLib, F 500ma 0603.STEP, PCBlib.PcbLib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]
2025-12-18 update dos outputs
    -outputs feitos para as mudanças anteriores
    [Teclas not fitted.GBL, Teclas not fitted.GBO, Teclas not fitted.GBP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]
2025-12-18 Corrections Nathan-Tosin
    [SqTeclado.SchDoc, teclado.PrjPcb]
2025-12-24 Corrigindo componentes e etc
    -diodos trocados pelos sugeridos
    -conector trocado, por um conector angulado
    -furos da borda alinhados) agora estão com todos estão com 4mm de distancia das bordas)
    -componentes da usb realinhados(acho que assim fica melhor)
    -arrumei as ligações duplas da usb usando áreas.
    *nota, não troquei o usb, o que foi sugerido não tinha pinos o suficientes
    -os arquivos de output para gerar a pcb estão atualizados
    [Diodo C.step, Esqlib.SchLib, PCBlib.PcbLib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]

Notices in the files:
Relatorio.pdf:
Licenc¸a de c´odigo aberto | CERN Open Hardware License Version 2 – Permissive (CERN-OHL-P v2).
